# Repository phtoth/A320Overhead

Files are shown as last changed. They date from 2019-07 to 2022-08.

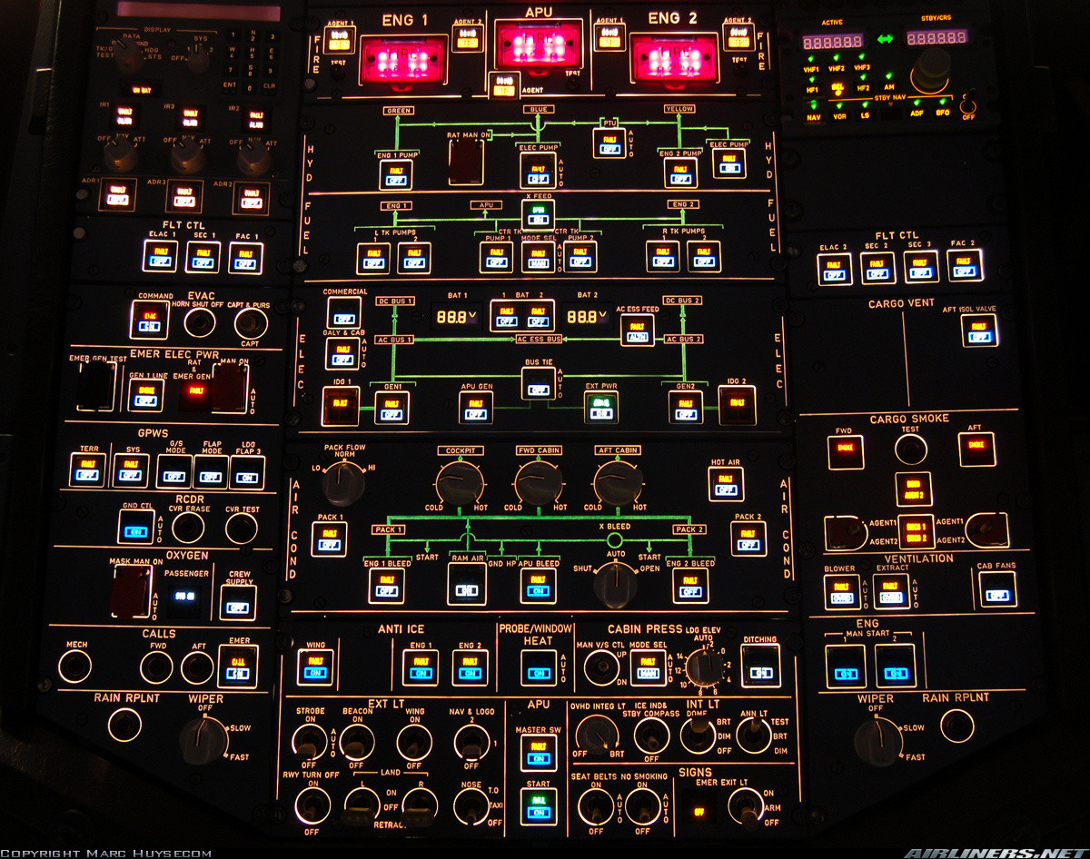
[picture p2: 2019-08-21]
Images that Help/crZPDkY.jpg

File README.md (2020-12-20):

# A320Overhead
A320 Overhead Project

Estrutura dos arquivos:
 - A320 AutoCAD Project - Projeto original do AutoCAD que está sendo modificado

 - Art - Os arquivos com os layouts originais da gravação a laser - com alguns erros :-(

 - Buttons - Projeto 3D dos botões dos painéis
      - Fire_Button - Botões de Controle de Incêndio
          - Button_Base - Base do botão que é colada na placa de acrílico
          - Button_Body - Corpo do Botão de Fire - o que mais demora para imprimir :-(
          - Button_Plate - Tampa com a inscrição "FIRE - Push"
          - Button_Extension - Mistakes Happen all the time

      - Korry - Botões no estilo Korry
          - Regular - Botões expostos, sem a proteção de acionamento
              - Horizontal - Apoio de fixação na horizontal do botão
              - Vertical - Apoio de fixação da vertical do botão
          - Stickers - Arquivos com os textos que ficam nos botões
      - Protected - Korrys que são protegidos    
          - Korry_Protected_Base - Base para segurar a capa de proteção do Korry
          - Korry_Protected_Shield - Capa protetora do Korry

      - Single_Protected_PB - Botões simples que são protegidos
          - Single_Protected_Base - Base dos botões que são protegidos
          - Single_Protected_Pin - Pino do botão
          - Single_Protected_Shield - Capa protetora dos botões protegidos
      - Button List.xlsx - Uma Lista com todos os botões do projeto

 - Eletronics - Arquivos com projetos e esquemeas eletricos e eletrônicos
      - Korry_Circuit - Circuitos que vão ficar atrás dos Korry Buttons
      - Led_Status - Placa que irá mostrar um status visual dos sistemas em execução
      - Main_Board - Placa principal do projeto, que irá acomodar os Arduinos e demais componentes

 - Images that Help - Alguns prints para ajudar na montagem do projeto

 - old - Coisas do projeto antigo - apagar no final

 - Panels - Diretório onde ficam os arquivos dos painéis
      - Light - Sistema de Iluminação do A320
          - Cut - Arquivo com os fontes para o corte a laser do painel
          - Draw - Arquivos para a pintura / gravação dos textos e setas
      - AirCond - Sistema de Ar Condicionado do A320
          - Cut - Arquivo com os fontes para o corte a laser do painel
          - Draw - Arquivos para a pintura / gravação dos textos e setas
      - Elec - Sistema Elétrico do A320
          - Cut - Arquivo com os fontes para o corte a laser do painel
          - Draw - Arquivos para a pintura / gravação dos textos e setas
      - Hyd_Fuel - Sistema Hidráulico e de Combustível do A320
          - Cut - Arquivo com os fontes para o corte a laser do painel
          - Draw - Arquivos para a pintura / gravação dos textos e setas
      - Fire - Sistema Supressão de Incêndio do A320
          - Cut - Arquivo com os fontes para o corte a laser do painel
          - Draw - Arquivos para a pintura / gravação dos textos e setas
      - Extra Size - Paineis do meio e Laterais para um tamanho extra no Overhead.
          - Cut - Arquivo com os fontes para o corte a laser do painel
      - Right Panel - Painel do Lado direito
          - R_Blank - Painel em Branco para preencher espaço vazio
                - Cut - Arquivo com os fontes para o corte a laser do painel
          - R_Cargo_Smoke - Sistema de supressão de incêndio no galpão de cargas e outros sistemas
                - Cut - Arquivo com os fontes para o corte a laser do painel
                - Draw - Arquivos para a pintura / gravação dos textos e setas
          - R_FLT_CTL - Sistema de Flight Control
                - Cut - Arquivo com os fontes para o corte a laser do painel
                - Draw - Arquivos para a pintura / gravação dos textos e setas
          - R_Radio_01_Blank - Sistema Rádio 01 - TODO
                - Cut - Arquivo com os fontes para o corte a laser do painel
          - R_Radio_02_Blank - Sistema Rádio 02 - TODO
                - Cut - Arquivo com os fontes para o corte a laser do painel
      - Left Panel - Painel do Lado esquerdo
          - L_ADIRS - Sistema de Navegação Inercial
                - Cut - Arquivo com os fontes para o corte a laser do painel
                - Draw - Arquivos para a pintura / gravação dos textos e setas
          - L_BAT - Painel onde fica a Luz ON BAT do Adirs
                - Cut - Arquivo com os fontes para o corte a laser do painel
          - L_Blank - Painel em Branco para preencher espaço vazio
                - Cut - Arquivo com os fontes para o corte a laser do painel
          - L_EVAC - Sistema de Emergência do avião
                - Cut - Arquivo com os fontes para o corte a laser do painel
                - Draw - Arquivos para a pintura / gravação dos textos e setas
          - L_FLT_CTL - Sistema de Flight Control
                - Cut - Arquivo com os fontes para o corte a laser do painel
                - Draw - Arquivos para a pintura / gravação dos textos e setas

  - Manuais - Documentações importantes
     - Componentes.md - Lista de componentes usados no projeto

  - README.md - Este arquivo :-)

Disclaimer: "Este é um projeto open source. Os pontos de vistas aqui apresentados são apenas meus e não foram revistos ou aprovados pela Airbus. Os códigos, prospectos e o projeto com oum todo foram criados por mim. Estes não pertecem e nem foram retirados da Airbus. Eu não falo em nome da Airbus. A marca Airbus A320® e todos os logotipos relacionados são marcas registradas da Airbus SE na França e demais países."

Disclaimer: "This is an open source project. The views presented here are only mine and have not been reviewed or approved by Airbus. The codes, prospectuses and the project as a whole were created by me. These do not belong nor have they been withdrawn of Airbus. I don't speak for Airbus. The Airbus A320® brand and all related logos are registered trademarks of Airbus SE in France and other countries."

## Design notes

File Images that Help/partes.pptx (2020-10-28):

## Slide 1

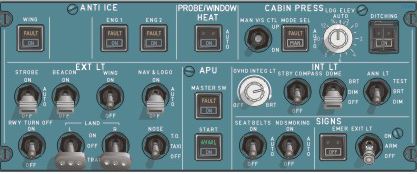
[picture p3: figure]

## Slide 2

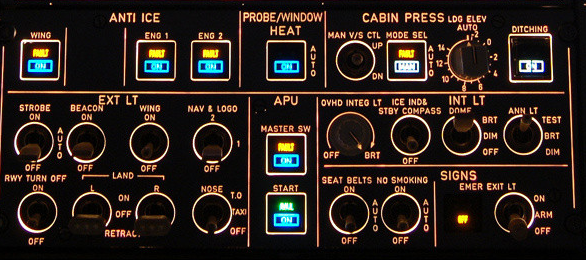
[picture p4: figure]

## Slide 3

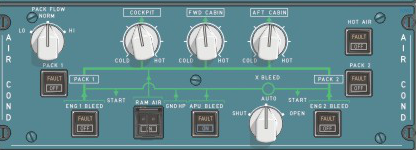
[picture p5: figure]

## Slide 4

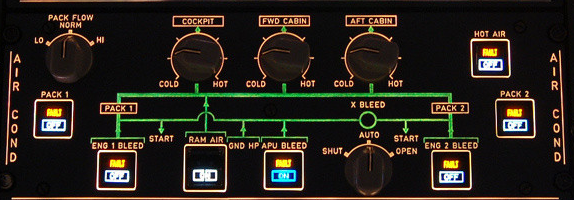
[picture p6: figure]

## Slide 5

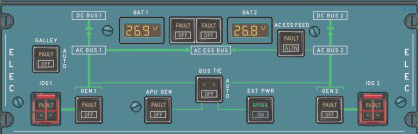
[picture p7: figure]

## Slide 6

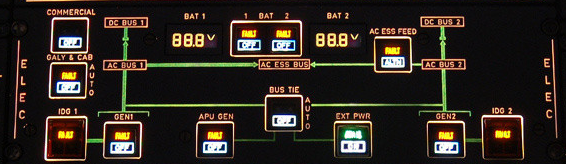
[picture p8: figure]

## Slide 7

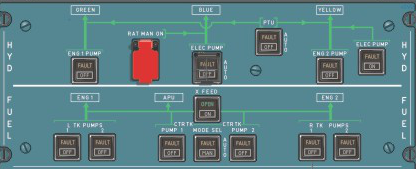
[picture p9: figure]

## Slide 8

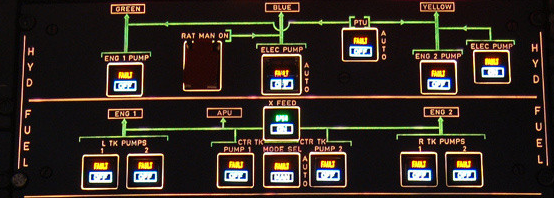
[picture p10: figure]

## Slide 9

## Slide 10

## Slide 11

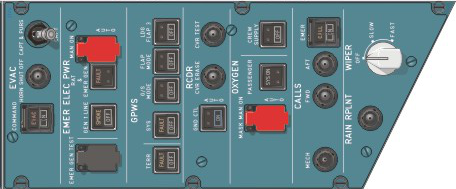
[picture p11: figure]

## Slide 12

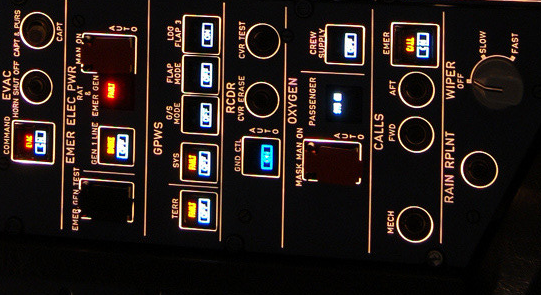
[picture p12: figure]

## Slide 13

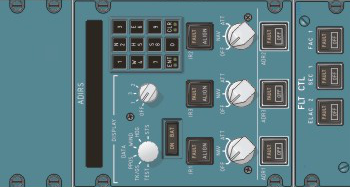
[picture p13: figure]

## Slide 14

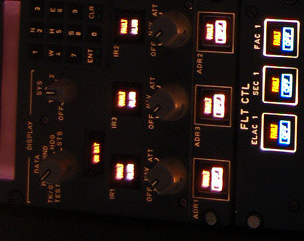
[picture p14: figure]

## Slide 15

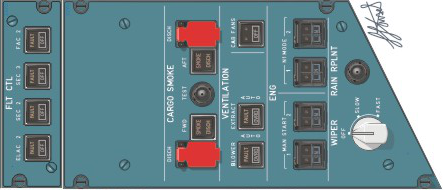
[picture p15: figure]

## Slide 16

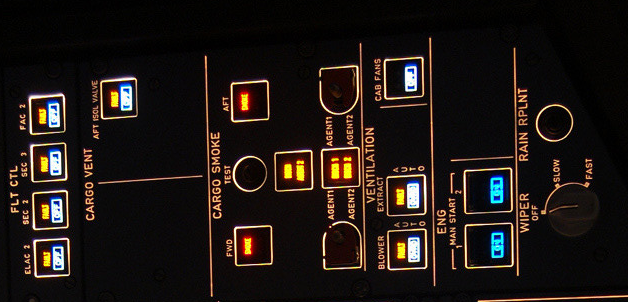
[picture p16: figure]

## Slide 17

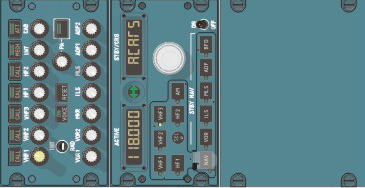
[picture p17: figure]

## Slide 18

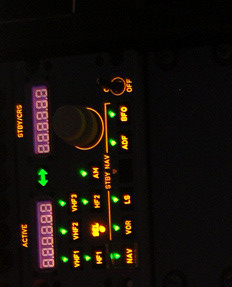
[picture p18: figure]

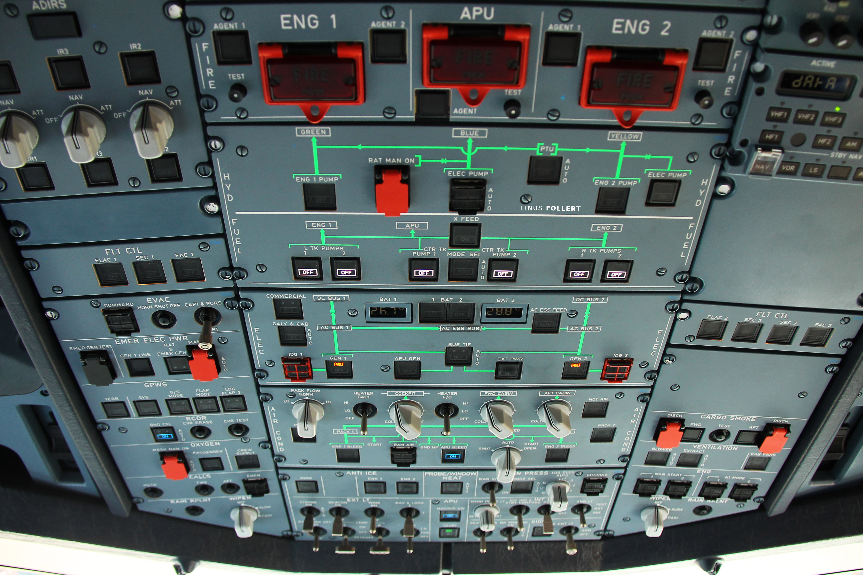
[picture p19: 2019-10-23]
Images that Help/14759350062_f6c9f7a548_o.jpg

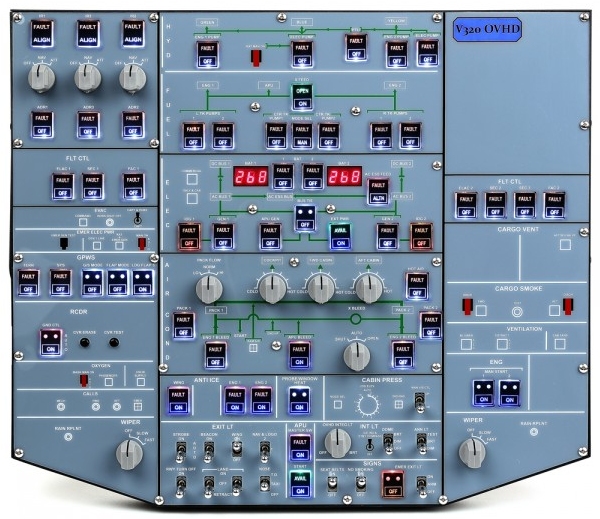
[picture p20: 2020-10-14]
Images that Help/VRI-225b.jpg

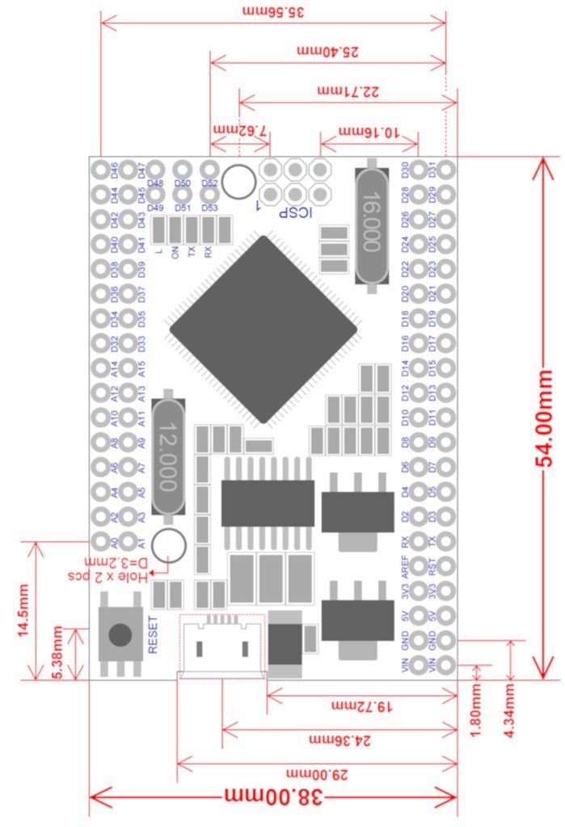
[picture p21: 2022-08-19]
Images that Help/ard-mega-pro_dimensions_zc_1024x1024.jpg

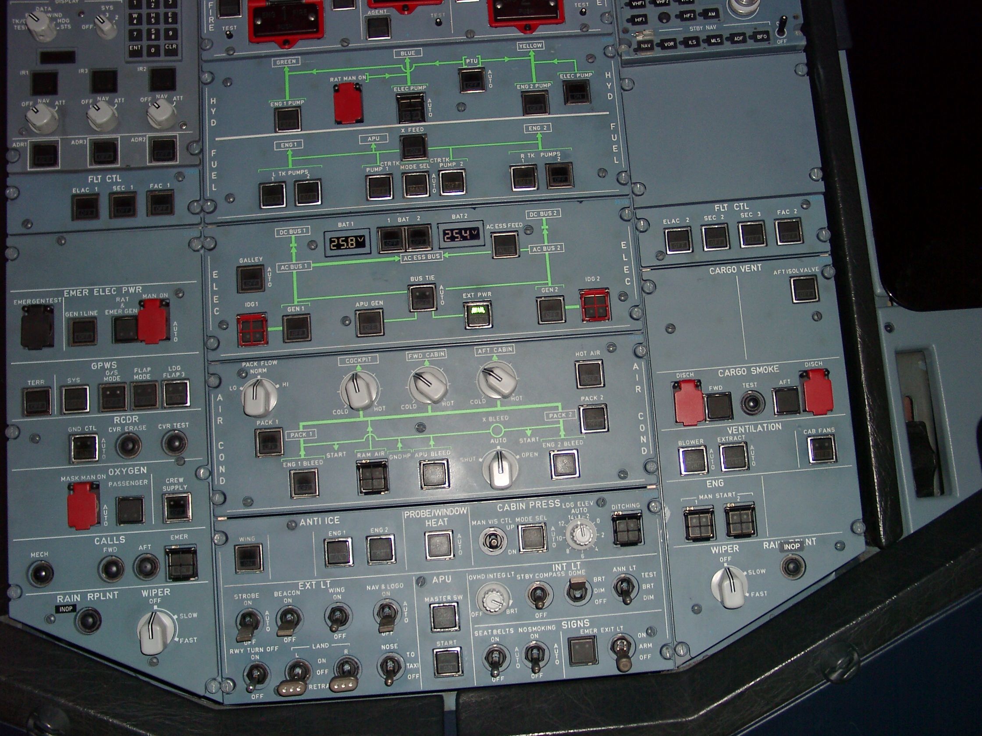
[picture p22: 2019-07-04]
Images that Help/lights.jpg

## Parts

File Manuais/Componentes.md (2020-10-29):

# Lista de componentes do Projeto
Segue a lista de materiais e quantidades necessárias para a montagem do projeto

## Compontente                                     Quantidade              Observação

Arduino MEGA 2560 Pro Mini ........................... 004 ................... 01                   
Arduino PORTENTA H7 .................................. 001 ................... 02
74HC595 - DIP ........................................ 032
Soquete para CI 16 pinos ............................. 032
Porta Fusível para Microondas de 30mm ................ 001 ................... 03 
Transistor Transistor NPN TIP41C ..................... 010
Dissipador de calor para TIP41C ...................... 010
Resistor 470 ohms (1/2/3 Watts) ...................... 010
Potenciometro Linear 47K ............................. 001
Soquete para CI 8 pinos .............................. 001
Cirtuito Integrado LM555 ............................. 001
Capacitor Cerâmico 100nF / 50V (104) ................. 002
Resistor 1K (1/2/3 Watts) ............................ 001
Relay SRD-05VDC-SL-C ................................. 003
Female Header 2.54 - 1x2 ............................. 004
Female Header 2.54 - 1x8 ............................. 008
Female Header 2.54 - 2x3 ............................. 008
Female Header 2.54 - 2x16 ............................ 004
Female Header 2.54 - 2x20 ............................ 004
Male / Female Header 2.54 - 1x1 ...................... 034 ................... 04
Male / Female Header 2.54 - 1x2 ...................... 005
Male / Female Header 2.54 - 1x3 ...................... 030
Male / Female Header 2.54 - 1x4 ...................... 001
Male / Female Header 2.54 - 1x5 ...................... 097
Male / Female Header 2.54 - 2x2 ...................... 001
Male / Female Header 2.54 - 2x5 ...................... 009
Male / Female Header 2.54 - 2x6 ...................... 007
Diodo 1N4007 ......................................... 014
Resistor 270 Ohms 1/4 Watt ........................... 181
Resistor 10K Ohm 1/4 Watt ............................ 144
Terminal KF128R-5.0-2P com passo de 5mm .............. 020

#### Obervações

01 - Se você for utilizar o Arduino Mega Mini como controlador geral do projeto, então a quantidade é 05.

02 - Se você Se você for utilizar o Arduino Mega Mini como controlador geral do projeto, então você não precisa deste componente. Ele foi escolhido para este projeto por sua capacidade dualcore. Cabe ressaltar também que vou me basear inicialmente no PORTENTA H7 como controlador principal, e que somente depois vou trabalhar em adaptações para o uso de um Mega Mini como controlador.

03 - Parecido com este: https://produto.mercadolivre.com.br/MLB-700023422-porta-fusivel-ceramica-20a-original-microondas-electrolux-_JM

04 - Os header marcados com Male / Female ficam a cargo do seu uso. Lembrando que, se você for usar conectores Male na placa, os seus conectores dos botões/leds deverão ser Female, e vice-versa.

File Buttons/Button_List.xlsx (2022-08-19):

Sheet: Iluminação
Codigo do Botão | Identificação | Tipo | Cod BTN | Orientação | QTD Leds | LED Bank | Cor 01 | LED Bank | Cor 02 | Texto 01 | Texto 02 | Tipo | Conexões Botão
1 | WING | Korry Regular | S_01_28_R | Horizontal | 2 | LED_BANK_04_A | Laranja | LED_BANK_04_B | Azul | FAULT | ON | Digital | 1
2 | ENG 1 | Korry Regular | S_01_29_R | Horizontal | 2 | LED_BANK_04_C | Laranja | LED_BANK_04_D | Azul | FAULT | ON | Digital | 1
3 | ENG 2 | Korry Regular | S_01_30_R | Horizontal | 2 | LED_BANK_04_E | Laranja | LED_BANK_04_F | Azul | FAULT | ON | Digital | 1
4 | STROBE | Seletor 3 Posições | S_01_04_R - S_01_05_R | - | - | - | - | - | - | - | - | Digital | 2
5 | BEACON | Seletor 2 Posições | S_01_24_R | - | - | - | - | - | - | - | - | Digital | 1
6 | WING | Seletor 2 Posições | S_01_25_R | - | - | - | - | - | - | - | - | Digital | 1
7 | NAV & LOGO | Seletor 3 Posições | S_01_06_R - S_01_07_R | - | - | - | - | - | - | - | - | Digital | 2
8 | RWY TURN OFF | Seletor 2 Posições | S_01_26_R | - | - | - | - | - | - | - | - | Digital | 1
9 | LAND L | Seletor 3 Posições | S_01_08_R - S_01_09_R | - | - | - | - | - | - | - | - | Digital | 2
10 | LAND R | Seletor 3 Posições | S_01_10_R - S_01_11_R | - | - | - | - | - | - | - | - | Digital | 2
11 | NOSE | Seletor 3 Posições | S_01_12_R - S_01_13_R | - | - | - | - | - | - | - | - | Digital | 2
12 | PROBE/WINDOW HEAT | Korry Regular | S_01_31_R | Horizontal | 1 | LED_BANK_04_G | - | - | Azul | - | ON | Digital | 1
13 | MASTER SW | Korry Regular | S_01_32_R | Horizontal | 2 | LED_BANK_04_H | Laranja | LED_BANK_05_A | Azul | FAULT | ON | Digital | 1
14 | START | Korry Regular | S_01_33_R | Horizontal | 2 | LED_BANK_05_B | Verde | LED_BANK_05_C | Azul | AVAIL | ON | Digital | 1
15 | MAN V/S CTL | Seletor 3 Posições | S_01_14_R - S_01_15_R | - | - | - | - | - | - | - | - | Digital | 2
16 | MODE SEL | Korry Regular | S_01_34_R | Horizontal | 2 | LED_BANK_05_D | Laranja | LED_BANK_05_E | Branco | FAULT | MAN | Digital | 1
17 | LDG ELEV | Seletor Livre | A01 | - | - |  | - |  | - |  |  | Analógico | 1
18 | DITCHING | Korry Protegido Preto | S_01_35_R | Horizontal | 1 | LED_BANK_05_F | - | - | Branco | - | ON | Digital | 1
19 | OVHD INTEG LT ** | Seletor Livre | *** | - | - | - | - | - | - | - | - | *** | ***
20 | ICE IND & STBY COMPASS | Seletor 2 Posições | S_01_27_R | - | - | - | - | - | - | - | - | Digital | 1
21 | DOME ** | Seletor 3 Posições | *** | - | - | - | - | - | - | - | - | *** | ***
22 | ANN LT | Seletor 3 Posições | S_01_16_R - S_01_17_R | - | - | - | - | - | - | - | - | Digital | 2
23 | SEAT BELTS | Seletor 3 Posições | S_01_18_R - S_01_19_R | - | - | - | - | - | - | - | - | Digital | 2
24 | NO SMOKING | Seletor 3 Posições | S_01_20_R - S_01_21_R | - | - | - | - | - | - | - | - | Digital | 2
25 | EMER | Korry Regular | S_01_36_R | Horizontal | 1 | LED_BANK_05_G | - | - | Laranja | - | OFF | Digital | 1
26 | EXIT LT | Seletor 3 Posições | S_01_22_R - S_01_23_R | - | - | - | - | - | - | - | - | Digital | 2
 |  |  |  |  |  |  |  |  |  |  | Entradas Digitais |  | 33
 |  |  |  |  |  |  |  |  |  |  | Entradas Analógicas |  | 1
 |  |  |  |  |  |  |  |  |  |  | Total de Leds |  | 15
 |  |  |  |  |  |  |  |  |  |  | Led Azul |  | 6
 |  |  |  |  |  |  |  |  |  |  | Led Laranja |  | 6
 |  |  |  |  |  |  |  |  |  |  | Led Branco |  | 2
 |  |  |  |  |  |  |  |  |  |  | Led Verde |  | 1
 |  |  |  |  |  |  |  |  |  |  | Conferência Leds |  | 15

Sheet: Ar Condicionado
Codigo do Botão | Identificação | Tipo | Cod BTN | Orientação | QTD Leds | LED Bank | Cor 01 | LED Bank | Cor 02 | Texto 01 | Texto 02 | Tipo | Conexões Botão
1 | PACK FLOW | Seletor Livre | A02 | - | - | - | - | - | - | - | - | Analógico | 1
2 | COCKPIT | Seletor Livre | A03 | - | - | - | - | - | - | - | - | Analógico | 1
3 | FWD CABIN | Seletor Livre | A04 | - | - | - | - | - | - | - | - | Analógico | 1
4 | AFT CABIN | Seletor Livre | A05 | - | - | - | - | - | - | - | - | Analógico | 1
5 | HOT AIR | Korry Regular | S_02_01_R | Horizontal | 2 | LED_BANK_05_H | Laranja | LED_BANK_06_A | Branco | FAULT | OFF | Digital | 1
6 | PACK 1 | Korry Regular | S_02_02_R | Horizontal | 2 | LED_BANK_06_B | Laranja | LED_BANK_06_C | Branco | FAULT | OFF | Digital | 1
7 | PACK2 | Korry Regular | S_02_03_R | Horizontal | 2 | LED_BANK_06_D | Laranja | LED_BANK_06_E | Branco | FAULT | OFF | Digital | 1
8 | ENG 1 BLEED | Korry Regular | S_02_04_R | Horizontal | 2 | LED_BANK_06_F | Laranja | LED_BANK_06_G | Branco | FAULT | OFF | Digital | 1
9 | RAM AIR | Korry Protegido Preto | S_02_05_R | Horizontal | 1 | - | - | LED_BANK_06_H | Branco | - | ON | Digital | 1
10 | APU BLEED | Korry Regular | S_02_06_R | Horizontal | 2 | LED_BANK_07_A | Laranja | LED_BANK_07_B | Azul | FAULT | ON | Digital | 1
11 | X-BLEED | Seletor Livre | A06 | - | - | - | - | - | - | - | - | Analógico | 1
12 | ENG 2 BLEED | Korry Regular | S_02_07_R | Horizontal | 2 | LED_BANK_07_C | Laranja | LED_BANK_07_D | Branco | FAULT | OFF | Digital | 1
 |  |  |  |  |  |  |  |  |  |  | Entradas Digitais |  | 7
 |  |  |  |  |  |  |  |  |  |  | Entradas Analógicas |  | 5
 |  |  |  |  |  |  |  |  |  |  | Total de Leds |  | 13
 |  |  |  |  |  |  |  |  |  |  | Led Azul |  | 1
 |  |  |  |  |  |  |  |  |  |  | Led Laranja |  | 6
 |  |  |  |  |  |  |  |  |  |  | Led Branco |  | 6
 |  |  |  |  |  |  |  |  |  |  | Conferência Leds |  | 13

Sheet: Elec
Codigo do Botão | Identificação | Tipo | Cod BTN | Orientação | QTD Leds | LED Bank | Cor 01 | LED Bank | Cor 02 | Texto 01 | Texto 02 | Tipo | Conexões Botão
1 | BAT 1 | Korry Regular | S_02_08_R | Vertical | 2 | LED_BANK_07_E | Laranja | LED_BANK_07_F | Branco | FAULT | OFF | Digital | 1
2 | BAT 2 | Korry Regular | S_02_09_R | Vertical | 2 | LED_BANK_07_G | Laranja | LED_BANK_07_H | Branco | FAULT | OFF | Digital | 1
3 | AC ESS FEED | Korry Regular | S_02_10_R | Horizontal | 2 | LED_BANK_08_A | Laranja | LED_BANK_08_B | Branco | FAULT | ALTN | Digital | 1
4 | GALLEY | Korry Regular | S_02_11_R | Horizontal | 2 | LED_BANK_08_C | Laranja | LED_BANK_08_D | Branco | FAULT | OFF | Digital | 1
5 | BUS TIE | Korry Regular | S_02_12_R | Horizontal | 1 | - | - | LED_BANK_08_E | Branco | - | OFF | Digital | 1
6 | IDG 1 | Korry Protegido Vermelho | S_02_13_R | Horizontal | 1 | LED_BANK_08_F | Laranja | - | - | FAULT | - | Digital | 1
7 | GEN 1 | Korry Regular | S_02_14_R | Horizontal | 2 | LED_BANK_08_G | Laranja | LED_BANK_08_H | Branco | FAULT | OFF | Digital | 1
8 | APU GEN | Korry Regular | S_02_15_R | Horizontal | 2 | LED_BANK_09_A | Laranja | LED_BANK_09_B | Branco | FAULT | OFF | Digital | 1
9 | EXT PWR | Korry Regular | S_02_16_R | Horizontal | 2 | LED_BANK_09_C | Verde | LED_BANK_09_D | Branco | AVAIL | ON | Digital | 1
10 | GEN 2 | Korry Regular | S_02_17_R | Horizontal | 2 | LED_BANK_09_E | Laranja | LED_BANK_09_F | Branco | FAULT | OFF | Digital | 1
11 | IDG 2 | Korry Protegido Vermelho | S_02_18_R | Horizontal | 1 | LED_BANK_09_G | Laranja | - | - | FAULT | - | Digital | 1
12 | LCD BAT 01 | DISPLAY Numérico | DISPLAY_01_01 - DISPLAY_01_03 | - | 24 | LED_BANK_10A-H | - |  | - | - | - | Digital | 3
12 | LCD BAT 02 | DISPLAY Numérico | DISPLAY_02_01 - DISPLAY_02_03 | - | 24 | LED_BANK_11A-H | - |  | - | - | - | Digital | 3
 |  |  |  |  |  |  |  |  |  |  | Entradas Digitais |  | 17
 |  |  |  |  |  |  |  |  |  |  | Entradas Analógicas |  | 0
 |  |  |  |  |  |  |  |  |  |  | Total de Leds |  | 67
 |  |  |  |  |  |  |  |  |  |  | Led Laranja |  | 9
 |  |  |  |  |  |  |  |  |  |  | Led Branco |  | 9
 |  |  |  |  |  |  |  |  |  |  | Led Verde |  | 1
 |  |  |  |  |  |  |  |  |  |  | Conferência Leds |  | 19

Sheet: Fuel
Codigo do Botão | Identificação | Tipo | Cod BTN | Orientação | QTD Leds | LED_Bank | Cor 01 | LED_Bank | Cor 02 | Texto 01 | Texto 02 | Tipo | Conexões Botão
1 | L TK PUMP 1 | Korry Regular | S_02_24_R | Vertical | 2 | LED_BANK_13_B | Laranja | LED_BANK_13_C | Branco | FAULT | OFF | Digital | 1
2 | L TK PUMP 2 | Korry Regular | S_02_19_R | Horizontal | 2 | LED_BANK_09_H | Laranja | LED_BANK_12_A | Branco | FAULT | OFF | Digital | 1
3 | X FEED | Korry Regular | S_02_20_R | Horizontal | 2 | LED_BANK_12_B | Verde | LED_BANK_12_C | Branco | OPEN | ON | Digital | 1
5 | CTR TK PUMP 1 | Korry Regular | S_02_21_R | Horizontal | 2 | LED_BANK_12_D | Laranja | LED_BANK_12_E | Branco | FAULT | OFF | Digital | 1
6 | MODE SEL | Korry Regular | S_02_25_R | Vertical | 2 | LED_BANK_13_D | Laranja | LED_BANK_13_E | Branco | FAULT | MAN | Digital | 1
7 | CTR TK PUMP 2 | Korry Regular | S_02_22_R | Horizontal | 2 | LED_BANK_12_F | Laranja | LED_BANK_12_G | Branco | FAULT | OFF | Digital | 1
8 | R TK PUMP 1 | Korry Regular | S_02_26_R | Vertical | 2 | LED_BANK_13_F | Laranja | LED_BANK_13_G | Branco | FAULT | OFF | Digital | 1
9 | R TK PUMP 2 | Korry Regular | S_02_23_R | Horizontal | 2 | LED_BANK_12_H | Laranja | LED_BANK_13_A | Branco | FAULT | OFF | Digital | 1
 |  |  |  |  |  |  |  |  |  |  | Entradas Digitais |  | 8
 |  |  |  |  |  |  |  |  |  |  | Entradas Analógicas |  | 0
 |  |  |  |  |  |  |  |  |  |  | Total de Leds |  | 16
 |  |  |  |  |  |  |  |  |  |  | Led Laranja |  | 7
 |  |  |  |  |  |  |  |  |  |  | Led Branco |  | 8
 |  |  |  |  |  |  |  |  |  |  | Led Verde |  | 1
 |  |  |  |  |  |  |  |  |  |  | Conferência Leds |  | 16

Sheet: Hyd
Codigo do Botão | Identificação | Tipo | Cod BTN | Orientação | QTD Leds | LED Bank | Cor 01 | LED Bank | Cor 02 | Texto 01 | Texto 02 | Tipo | Conexões Botão
1 | ENG 1 PUMP | Korry Regular | S_02_27_R | Horizontal | 2 | LED_BANK_13_H | Laranja | LED_BANK_14_A | Branco | FAULT | OFF | Digital | 1
2 | RAT MAN ON | Botão Com Capa Vermelha Fechada | S_02_28_R | - | 1 | LED_BANK_14_B | Branco | - | - | - | - | Digital | 1
3 | ELEC PUMP | Korry Protegido Preto | S_02_29_R | Horizontal | 2 | LED_BANK_14_C | Laranja | LED_BANK_14_D | Branco | FAULT | OFF | Digital | 1
5 | PTU | Korry Regular | S_02_30_R | Horizontal | 2 | LED_BANK_14_E | Laranja | LED_BANK_14_F | Branco | FAULT | OFF | Digital | 1
6 | ENG 2 PUMP | Korry Regular | S_02_31_R | Horizontal | 2 | LED_BANK_14_G | Laranja | LED_BANK_14_H | Branco | FAULT | OFF | Digital | 1
7 | ELEC PUMP | Korry Regular | S_02_32_R | Horizontal | 2 | LED_BANK_15_A | Laranja | LED_BANK_15_B | Branco | FAULT | ON | Digital | 1
 |  |  |  |  |  |  |  |  |  |  | Entradas Digitais |  | 6
 |  |  |  |  |  |  |  |  |  |  | Entradas Analógicas |  | 0
 |  |  |  |  |  |  |  |  |  |  | Total de Leds |  | 11
 |  |  |  |  |  |  |  |  |  |  | Led Laranja |  | 5
 |  |  |  |  |  |  |  |  |  |  | Led Branco |  | 6
 |  |  |  |  |  |  |  |  |  |  | Conferência Leds |  | 11

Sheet: Fire
Codigo do Botão | Identificação | Tipo | Cod BTN | Orientação | QTD Leds | LED Bank | Cor 01 | LED_Bank | Cor 02 | Texto 01 | Texto 02 | Tipo | Conexões Botão
1 | AGENT 1 | Korry Regular | S_02_33_R | Horizontal | 2 | LED_BANK_15_C | Branco | LED_BANK_15_D | Laranja | SQUIB | DISCH | Digital | 1
2 | TEST | Botão Simples | S_02_34_R | - | 1 | LED_BANK_15_E | Branco | - | - | - | - | Digital | 1
3 | ENG 1 FIRE | Botão Vermelho com Proteção Vermelha | S_01_01_R | - | 8 | LED_BANK_1_A--H | Vermelho | - | Vermelho | - | - | Digital | 1
5 | AGENT 2 | Korry Regular | S_02_35_R | Horizontal | 2 | LED_BANK_15_F | Branco | LED_BANK_15_G | Laranja | SQUIB | DISCH | Digital | 1
6 | APU FIRE | Botão Vermelho com Proteção Vermelha | S_01_02_R | - | 8 | LED_BANK_2_A--H | Vermelho | - | Vermelho | - | - | Digital | 1
7 | AGENT | Korry Regular | S_02_36_R | Horizontal | 2 | LED_BANK_15_H | Branco | LED_BANK_16_A | Laranja | SQUIB | DISCH | Digital | 1
10 | TEST | Botão Simples | S_03_01_R | - | 1 | LED_BANK_16_B | Branco | - | - | - | - | Digital | 1
11 | AGENT 1 | Korry Regular | S_03_02_R | Horizontal | 2 | LED_BANK_16_C | Branco | LED_BANK_16_D | Laranja | SQUIB | DISCH | Digital | 1
12 | ENG 2 FIRE | Botão Vermelho com Proteção Vermelha | S_01_03_R | - | 8 | LED_BANK_3_A--H | Vermelho | - | Vermelho | - | - | Digital | 1
13 | TEST | Botão Simples | S_03_03_R | - | 1 | LED_BANK_16_E | Branco | - | - | - | - | Digital | 1
14 | AGENT 2 | Korry Regular | S_03_04_R | Horizontal | 2 | LED_BANK_16_F | Branco | LED_BANK_16_G | Laranja | SQUIB | DISCH | Digital | 1
 |  |  |  |  |  |  |  |  |  |  | Entradas Digitais |  | 11
 |  |  |  |  |  |  |  |  |  |  | Entradas Analógicas |  | 0
 |  |  |  |  |  |  |  |  |  |  | Total de Leds |  | 37
 |  |  |  |  |  |  |  |  |  |  | Led Laranja |  | 5
 |  |  |  |  |  |  |  |  |  |  | Led Branco |  | 8
 |  |  |  |  |  |  |  |  |  |  | Led Vermelho |  | 24
 |  |  |  |  |  |  |  |  |  |  | Conferência Leds |  | 37

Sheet: Right_Side
Codigo do Botão | Identificação | Tipo | Cod BTN | Orientação | QTD Leds | LED Bank | Cor 01 | LED Bank | Cor 02 | Texto 01 | Texto 02 | Tipo | Conexões Botão
1 | WIPER | Seletor Livre | A07 | - | - | - | - | - | - | - | - | Analógico | 1
2 | RAIN RPLNT | Botão Simples | S_03_05_R | - | 1 | LED_BANK_16_H | Branco | - | - | - | - | Digital | 1
3 | ENG MAN START 1 | Korry Protegido Preto | S_03_06_R | Horizontal | 1 | - | - | LED_BANK_17_A | Azul | - | ON | Digital | 1
6 | N1 MODE 1 | Korry Protegido Preto | S_03_07_R | Horizontal | 1 | - | - | LED_BANK_17_B | Azul | - | ON | Digital | 1
10 | BLOWER | Korry Regular | S_03_08_R | Horizontal | 2 | LED_BANK_17_C | Laranja | LED_BANK_17_D | Branco | FAULT | OVRD | Digital | 1
11 | EXTRACT | Korry Regular | S_03_09_R | Horizontal | 2 | LED_BANK_17_E | Laranja | LED_BANK_17_F | Branco | FAULT | OVRD | Digital | 1
12 | CAB FANS | Korry Regular | S_03_10_R | Horizontal | 1 | - | - | LED_BANK_17_G | Branco | - | OFF | Digital | 1
13 | ELAC 2 | Korry Regular | S_03_11_R | Horizontal | 2 | LED_BANK_17_H | Laranja | LED_BANK_18_A | Branco | FAULT | OFF | Digital | 1
14 | SEC 3 | Korry Regular | S_03_12_R | Horizontal | 2 | LED_BANK_18_B | Laranja | LED_BANK_18_C | Branco | FAULT | OFF | Digital | 1
15 | DISCH | Botão Com Capa Vermelha Fechada | S_03_13_R | - | 1 | LED_BANK_18_D | Branco | - | - | - | - | Digital | 1
16 | ENG MAN START 2 | Korry Protegido Preto | S_03_14_R | Vertical | 1 | - | - | LED_BANK_18_E | Azul | - | ON | Digital | 1
17 | TEST | Botão Simples | S_03_15_R | - | 1 | LED_BANK_18_F | Branco | - | - | - | - | Digital | 1
18 | N1 MODE 2 | Korry Protegido Preto | S_03_16_R | Vertical | 1 | - | - | LED_BANK_18_G | Azul | - | ON | Digital | 1
19 | DISCH | Botão Com Capa Vermelha Fechada | S_03_17_R | - | 1 | LED_BANK_18_H | Branco | - | - | - | - | Digital | 1
20 | FWD | Korry Regular | S_03_18_R | Vertical | 2 | LED_BANK_19_A | Vermelho | LED_BANK_19_B | Laranja | SMOKE | DISCH | Digital | 1
21 | AFT | Korry Regular | S_03_19_R | Vertical | 2 | LED_BANK_19_C | Vermelho | LED_BANK_19_D | Laranja | SMOKE | DISCH | Digital | 1
22 | SEC 2 | Korry Regular | S_03_20_R | Vertical | 2 | LED_BANK_19_E | Laranja | LED_BANK_19_F | Branco | FAULT | OFF | Digital | 1
23 | FAC 3 | Korry Regular | S_03_21_R | Vertical | 2 | LED_BANK_19_G | Laranja | LED_BANK_19_H | Branco | FAULT | OFF | Digital | 1
 |  |  |  |  |  |  |  |  |  |  | Entradas Digitais |  | 17
 |  |  |  |  |  |  |  |  |  |  | Entradas Analógicas |  | 1
 |  |  |  |  |  |  |  |  |  |  | Total de Leds |  | 25
 |  |  |  |  |  |  |  |  |  |  | Led Laranja |  | 8
 |  |  |  |  |  |  |  |  |  |  | Led Branco |  | 11
 |  |  |  |  |  |  |  |  |  |  | Led Azul |  | 4
 |  |  |  |  |  |  |  |  |  |  | Led Vermelho |  | 2
 |  |  |  |  |  |  |  |  |  |  | Conferência Leds |  | 25

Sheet: Left_Side
Codigo do Botão | Identificação | Tipo | Cod BTN | Orientação | QTD Leds | LED Bank | Cor 01 | LED Bank | Cor 02 | Texto 01 | Texto 02 | Tipo | Conexões Botão
1 | WIPER | Seletor Livre | A08 | - | - | - | - | - | - | - | - | Analógico | 1
2 | RAIN RPLNT | Botão Simples | S_03_22_R | - | 1 | LED_BANK_20_A | Branco | - | - | - | - | Digital | 1
3 | EMER | Korry Protegido Preto | S_03_23_R | Horizontal | 2 | LED_BANK_20_B | Laranja | LED_BANK_20_C | Vermelho | CALL | ON | Digital | 1
6 | MECH | Botão Simples | S_03_24_R | - | 1 | LED_BANK_20_D | Branco | - | - | - | - | Digital | 1
10 | FWD | Botão Simples | S_03_25_R | - | 1 | LED_BANK_20_E | Branco | - | - | - | - | Digital | 1
11 | AFT | Botão Simples | S_03_26_R | - | 1 | LED_BANK_20_F | Branco | - | - | - | - | Digital | 1
12 | MASK MAN ON | Botão Com Capa Vermelha Fechada | S_03_27_R | - | 1 | LED_BANK_20_G | Branco | - | - | - | - | Digital | 1
13 | PASSENGER | Korry Regular | S_03_28_R | Horizontal | 1 | LED_BANK_20_H | Branco | - | - | SYS ON | - | Digital | 1
14 | CREW SUPPLY | Korry Regular | S_03_29_R | Horizontal | 1 | LED_BANK_21_A | Branco | - | - | - | OFF | Digital | 1
15 | GND CTL | Korry Regular | S_03_30_R | Horizontal | 1 | - | - | LED_BANK_21_B | Azul | - | ON | Digital | 1
16 | CVR ERASE | Botão Simples | S_03_31_R | - | 1 | LED_BANK_21_C | Branco | - | - | - | - | Digital | 1
17 | CVR TEST | Botão Simples | S_03_32_R | - | 1 | LED_BANK_21_D | Branco | - | - | - | - | Digital | 1
18 | TERR | Korry Regular | S_03_33_R | Horizontal | 2 | LED_BANK_21_E | Laranja | LED_BANK_21_F | Branco | FAULT | OFF | Digital | 1
19 | G/S MODE | Korry Regular | S_03_34_R | Horizontal | 1 | - | - | LED_BANK_21_G | Branco | - | OFF | Digital | 1
20 | LDG FLAP 3 | Korry Regular | S_03_35_R | Horizontal | 1 | - | - | LED_BANK_21_H | Branco | - | ON | Digital | 1
21 | GEN 1 LINE | Korry Regular | S_03_36_R | Horizontal | 2 | LED_BANK_22_A | Laranja | LED_BANK_22_B | Branco | SMOKE | OFF | Digital | 1
22 | COMMAND | Korry Protegido Preto | S_04_01_R | Horizontal | 2 | LED_BANK_22_C | Vermelho | LED_BANK_22_D | Branco | EVAC | ON | Digital | 1
23 | EMER GEN TEST | Botão Com Capa Preta Fechada | S_04_02_R | - | 1 | LED_BANK_22_E | Branco | - | - | - | - | Digital | 1
24 | ELAC 1 | Korry Regular | S_04_03_R | Horizontal | 2 | LED_BANK_22_F | Laranja | LED_BANK_22_G | Branco | FAULT | OFF | Digital | 1
25 | FAC 1 | Korry Regular | S_04_04_R | Horizontal | 2 | LED_BANK_22_H | Laranja | LED_BANK_23_A | Branco | FAULT | OFF | Digital | 1
26 | MAN ON | Botão Com Capa Vermelha Fechada | S_04_05_R | - | 1 | LED_BANK_23_B | Branco | - | - | - | - | Digital | 1
27 | ADR 1 | Korry Regular | S_04_06_R | Horizontal | 2 | LED_BANK_23_C | Laranja | LED_BANK_23_D | Branco | FAULT | OFF | Digital | 1
28 | HORN SHUT OFF | Botão Simples | S_04_07_R | - | 1 | LED_BANK_23_E | Branco | - | - | - | - | Digital | 1
29 | CAPT & PURS | Seletor 3 Posições | S_04_08_R - S_04_09_R | - | - | - | - | - | - | - | - | Digital | 2
30 | ADR 3 | Korry Regular | S_04_10_R | Horizontal | 2 | LED_BANK_23_F | Laranja | LED_BANK_23_G | Branco | FAULT | OFF | Digital | 1
31 | ADR 2 | Korry Regular | S_04_11_R | Horizontal | 2 | LED_BANK_23_H | Laranja | LED_BANK_24_A | Branco | FAULT | OFF | Digital | 1
32 | IR 1 | Korry Regular | S_04_12_R | Horizontal | 2 | LED_BANK_24_B | Laranja | LED_BANK_24_C | Branco | FAULT | ALIGN | Digital | 1
33 | IR 3 | Korry Regular | S_04_13_R | Horizontal | 2 | LED_BANK_24_D | Laranja | LED_BANK_24_E | Branco | FAULT | ALIGN | Digital | 1
34 | IR 2 | Korry Regular | S_04_14_R | Horizontal | 2 | LED_BANK_24_F | Laranja | LED_BANK_24_G | Branco | FAULT | ALIGN | Digital | 1
35 | SYS | Korry Regular | S_04_15_R | Vertical | 2 | LED_BANK_24_H | Laranja | LED_BANK_25_A | Branco | FAULT | OFF | Digital | 1
36 | NAV | Seletor Livre | A09 | - | - | - | - | - | - | - | - | Analógico | 1
37 | NAV | Seletor Livre | A10 | - | - | - | - | - | - | - | - | Analógico | 1
38 | NAV | Seletor Livre | A11 | - | - | - | - | - | - | - | - | Analógico | 1
39 | FLAP MODE | Korry Regular | S_04_16_R | Vertical | 1 | - | - | LED_BANK_25_B | Branco | - | OFF | Digital | 1
40 | RAT & EMER GEN | Korry Regular | S_04_17_R | Vertical | 1 | LED_BANK_25_C | Vermelho | - | - | FAULT | - | Digital | 1
41 | SEC 1 | Korry Regular | S_04_18_R | Vertical | 2 | LED_BANK_25_D | Laranja | LED_BANK_25_E | Branco | FAULT | OFF | Digital | 1
 |  |  |  |  |  |  |  |  |  |  | Entradas Digitais |  | 33
 |  |  |  |  |  |  |  |  |  |  | Entradas Analógicas |  | 4
 |  |  |  |  |  |  |  |  |  |  | Total de Leds |  | 45
 |  |  |  |  |  |  |  |  |  |  | Led Laranja |  | 13
 |  |  |  |  |  |  |  |  |  |  | Led Branco |  | 28
 |  |  |  |  |  |  |  |  |  |  | Led Azul |  | 1
 |  |  |  |  |  |  |  |  |  |  | Led Vermelho |  | 3
 |  |  |  |  |  |  |  |  |  |  | Conferência Leds |  | 45

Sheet: Totais
E/S Digital | 132
E/S Analógico | 11
Leds | 229
Led Driver | 29
E/S Digital + Led Drivers | 156
Controladoras CAN - Módulos | 6
E/S Dig + Led Drivers + CAN | 186
Número de Arduino - Módulos | 3
Arduino Master - Interface | 1
Led Laranja | 59
Led Azul | 12
Led Verde | 3
Led Branco | 78
Led Vermelho | 29
Displays Numéricos | 48
Conferência de Leds | 229

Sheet: Board_01_Buttons
Cod | Nome | Pinout | Tipo | Códigos Internos / Valores
1 | LDG ELEV | A01 | Analog | 100 | 0-255 | -
1 | ENG 1 FIRE | S_01_01_R | Korry | 1 | 2 | -
2 | PACK FLOW | A02 | Analog | 101 | 0-255 | -
2 | APU FIRE | S_01_02_R | Korry | 3 | 4 | -
3 | COCKPIT | A03 | Analog | 102 | 0-255 | -
3 | ENG 2 FIRE | S_01_03_R | Korry | 5 | 6 | -
4 | STROBE | S_01_05_R | 3 Pole | 7 | 8 | 9
4 | STROBE | S_01_04_R | 3 Pole | 10 | 11 | 12
4 | FWD CABIN | A04 | Analog | 103 | 0-255 | -
5 | NAV & LOGO | S_01_06_R | 3 Pole | 13 | 14 | 15
5 | NAV & LOGO | S_01_07_R | 3 Pole | 16 | 17 | 18
6 | LAND L | S_01_08_R | 3 Pole | 19 | 20 | 21
6 | LAND L | S_01_09_R | 3 Pole | 22 | 23 | 24
7 | LAND R | S_01_10_R | 3 Pole | 25 | 26 | 27
7 | LAND R | S_01_11_R | 3 Pole | 28 | 29 | 30
8 | NOSE | S_01_12_R | 3 Pole | 31 | 32 | 33
8 | NOSE | S_01_13_R | 3 Pole | 34 | 35 | 36
9 | MAN V/S CTL | S_01_14_R | 3 Pole | 37 | 38 | 39
9 | MAN V/S CTL | S_01_15_R | 3 Pole | 40 | 41 | 42
10 | ANN LT | S_01_16_R | 3 Pole | 43 | 44 | 45
10 | ANN LT | S_01_17_R | 3 Pole | 46 | 47 | 48
11 | SEAT BELTS | S_01_18_R | 3 Pole | 49 | 50 | 51
11 | SEAT BELTS | S_01_19_R | 3 Pole | 52 | 53 | 54
12 | NO SMOKING | S_01_20_R | 3 Pole | 55 | 56 | 57
12 | NO SMOKING | S_01_21_R | 3 Pole | 58 | 59 | 60
13 | EXIT LT | S_01_22_R | 3 Pole | 61 | 62 | 63
13 | EXIT LT | S_01_23_R | 3 Pole | 64 | 65 | 66
14 | BEACON | S_01_24_R | 2 Pole | 67 | 68 | -
15 | WING | S_01_25_R | 2 Pole | 69 | 70 | -
16 | RWY TURN OFF | S_01_26_R | 2 Pole | 71 | 72 | -
17 | ICE IND & STBY COMPASS | S_01_27_R | 2 Pole | 73 | 74 | -
18 | WING | S_01_28_R | Korry | 75 | 76 | -
19 | ENG 1 | S_01_29_R | Korry | 77 | 78 | -
20 | ENG 2 | S_01_30_R | Korry | 79 | 80 | -
21 | PROBE/WINDOW HEAT | S_01_31_R | Korry | 81 | 82 | -
22 | MASTER SW | S_01_32_R | Korry | 83 | 84 | -
23 | START | S_01_33_R | Korry | 85 | 86 | -
24 | MODE SEL | S_01_34_R | Korry | 87 | 88 | -
25 | DITCHING | S_01_35_R | Korry | 89 | 90 | -
26 | EMER | S_01_36_R | Korry | 91 | 92 | -

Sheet: Board_01_Leds
1 | A | Led_Bank_1 | ENG 1 FIRE
1 | B | Led_Bank_1 | ENG 1 FIRE
1 | C | Led_Bank_1 | ENG 1 FIRE
1 | D | Led_Bank_1 | ENG 1 FIRE
1 | E | Led_Bank_1 | ENG 1 FIRE
1 | F | Led_Bank_1 | ENG 1 FIRE
1 | G | Led_Bank_1 | ENG 1 FIRE
1 | H | Led_Bank_1 | ENG 1 FIRE
2 | A | Led_Bank_2 | APU FIRE
2 | B | Led_Bank_2 | APU FIRE
2 | C | Led_Bank_2 | APU FIRE
2 | D | Led_Bank_2 | APU FIRE
2 | E | Led_Bank_2 | APU FIRE
2 | F | Led_Bank_2 | APU FIRE
2 | G | Led_Bank_2 | APU FIRE
2 | H | Led_Bank_2 | APU FIRE
3 | A | Led_Bank_3 | ENG 2 FIRE
3 | B | Led_Bank_3 | ENG 2 FIRE
3 | C | Led_Bank_3 | ENG 2 FIRE
3 | D | Led_Bank_3 | ENG 2 FIRE
3 | E | Led_Bank_3 | ENG 2 FIRE
3 | F | Led_Bank_3 | ENG 2 FIRE
3 | G | Led_Bank_3 | ENG 2 FIRE
3 | H | Led_Bank_3 | ENG 2 FIRE
4 | A | Led_Bank_4 | WING
4 | B | Led_Bank_4 | WING
5 | C | Led_Bank_4 | ENG 1
5 | D | Led_Bank_4 | ENG 1
6 | E | Led_Bank_4 | ENG 2
6 | F | Led_Bank_4 | ENG 2
7 | G | Led_Bank_4 | PROBE/WINDOW HEAT
8 | H | Led_Bank_4 | MASTER SW
8 | A | Led_Bank_5 | MASTER SW
9 | B | Led_Bank_5 | START
9 | C | Led_Bank_5 | START
10 | D | Led_Bank_5 | MODE SEL
10 | E | Led_Bank_5 | MODE SEL
11 | F | Led_Bank_5 | DITCHING
12 | G | Led_Bank_5 | EMER
13 | H | Led_Bank_5 | HOT AIR
13 | A | Led_Bank_6 | HOT AIR
14 | B | Led_Bank_6 | PACK 1
14 | C | Led_Bank_6 | PACK 1
15 | D | Led_Bank_6 | PACK2
15 | E | Led_Bank_6 | PACK2
16 | F | Led_Bank_6 | ENG 1 BLEED
16 | G | Led_Bank_6 | ENG 1 BLEED
17 | H | Led_Bank_6 | RAM AIR
18 | A | Led_Bank_7 | APU BLEED
18 | B | Led_Bank_7 | APU BLEED
19 | C | Led_Bank_7 | ENG 2 BLEED
19 | D | Led_Bank_7 | ENG 2 BLEED
20 | E | Led_Bank_7 | BAT 1
20 | F | Led_Bank_7 | BAT 1
21 | G | Led_Bank_7 | BAT 2
21 | H | Led_Bank_7 | BAT 2
22 | A | Led_Bank_8 | AC ESS FEED
22 | B | Led_Bank_8 | AC ESS FEED
23 | C | Led_Bank_8 | GALLEY
23 | D | Led_Bank_8 | GALLEY
24 | E | Led_Bank_8 | BUS TIE
25 | F | Led_Bank_8 | IDG 1
26 | G | Led_Bank_8 | GEN 1
26 | H | Led_Bank_8 | GEN 1

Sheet: Board_02_Buttons
1 | HOT AIR | S_02_01_R
2 | PACK 1 | S_02_02_R
3 | PACK2 | S_02_03_R
4 | ENG 1 BLEED | S_02_04_R
5 | RAM AIR | S_02_05_R
6 | APU BLEED | S_02_06_R
7 | ENG 2 BLEED | S_02_07_R
8 | BAT 1 | S_02_08_R
9 | BAT 2 | S_02_09_R
10 | AC ESS FEED | S_02_10_R
11 | GALLEY | S_02_11_R
12 | BUS TIE | S_02_12_R
13 | IDG 1 | S_02_13_R
14 | GEN 1 | S_02_14_R
15 | APU GEN | S_02_15_R
16 | EXT PWR | S_02_16_R
17 | GEN 2 | S_02_17_R
18 | IDG 2 | S_02_18_R
19 | L TK PUMP 2 | S_02_19_R
20 | X FEED | S_02_20_R
21 | CTR TK PUMP 1 | S_02_21_R
22 | CTR TK PUMP 2 | S_02_22_R
23 | R TK PUMP 2 | S_02_23_R
24 | L TK PUMP 1 | S_02_24_R
25 | MODE SEL | S_02_25_R
26 | R TK PUMP 1 | S_02_26_R
27 | ENG 1 PUMP | S_02_27_R
28 | RAT MAN ON | S_02_28_R
29 | ELEC PUMP | S_02_29_R
30 | PTU | S_02_30_R
31 | ENG 2 PUMP | S_02_31_R
32 | ELEC PUMP | S_02_32_R
33 | AGENT 1 | S_02_33_R
34 | TEST | S_02_34_R
35 | AGENT 2 | S_02_35_R
36 | AGENT | S_02_36_R
1 | AFT CABIN | A05
2 | X-BLEED | A06
3 | WIPER | A07
4 | WIPER | A08

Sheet: Board_02_Leds
1 | A | Led_Bank_9 | APU GEN
1 | B | Led_Bank_9 | APU GEN
2 | C | Led_Bank_9 | EXT PWR
2 | D | Led_Bank_9 | EXT PWR
3 | E | Led_Bank_9 | GEN 2
3 | F | Led_Bank_9 | GEN 2
4 | G | Led_Bank_9 | IDG 2
5 | H | Led_Bank_9 | L TK PUMP 2
6 | A | Led_Bank_10 | LCD BAT 01
6 | B | Led_Bank_10 | LCD BAT 01
6 | C | Led_Bank_10 | LCD BAT 01
6 | D | Led_Bank_10 | LCD BAT 01
6 | E | Led_Bank_10 | LCD BAT 01
6 | F | Led_Bank_10 | LCD BAT 01
6 | G | Led_Bank_10 | LCD BAT 01
6 | H | Led_Bank_10 | LCD BAT 01
7 | A | Led_Bank_11 | LCD BAT 02
7 | B | Led_Bank_11 | LCD BAT 02
7 | C | Led_Bank_11 | LCD BAT 02
7 | D | Led_Bank_11 | LCD BAT 02
7 | E | Led_Bank_11 | LCD BAT 02
7 | F | Led_Bank_11 | LCD BAT 02
7 | G | Led_Bank_11 | LCD BAT 02
7 | H | Led_Bank_11 | LCD BAT 02
5 | A | Led_Bank_12 | L TK PUMP 2
8 | B | Led_Bank_12 | L TK PUMP 1
8 | C | Led_Bank_12 | L TK PUMP 1
9 | D | Led_Bank_12 | CTR TK PUMP 1
9 | E | Led_Bank_12 | CTR TK PUMP 1
10 | F | Led_Bank_12 | CTR TK PUMP 2
10 | G | Led_Bank_12 | CTR TK PUMP 2
11 | H | Led_Bank_12 | R TK PUMP 2
11 | A | Led_Bank_13 | R TK PUMP 2
12 | B | Led_Bank_13 | L TK PUMP 1
12 | C | Led_Bank_13 | L TK PUMP 1
13 | D | Led_Bank_13 | MODE SEL
13 | E | Led_Bank_13 | MODE SEL
14 | F | Led_Bank_13 | R TK PUMP 1
14 | G | Led_Bank_13 | R TK PUMP 1
15 | H | Led_Bank_13 | ENG 1 PUMP
15 | A | Led_Bank_14 | ENG 1 PUMP
16 | B | Led_Bank_14 | RAT MAN ON
17 | C | Led_Bank_14 | ELEC PUMP
17 | D | Led_Bank_14 | ELEC PUMP
18 | E | Led_Bank_14 | PTU
18 | F | Led_Bank_14 | PTU
19 | G | Led_Bank_14 | ENG 2 PUMP
19 | H | Led_Bank_14 | ENG 2 PUMP
20 | A | Led_Bank_15 | ELEC PUMP
20 | B | Led_Bank_15 | ELEC PUMP
21 | C | Led_Bank_15 | AGENT 1
21 | D | Led_Bank_15 | AGENT 1
22 | E | Led_Bank_15 | TEST
23 | F | Led_Bank_15 | AGENT 2
23 | G | Led_Bank_15 | AGENT 2
24 | H | Led_Bank_15 | AGENT
24 | A | Led_Bank_16 | AGENT
25 | B | Led_Bank_16 | TEST
26 | C | Led_Bank_16 | AGENT 1
26 | D | Led_Bank_16 | AGENT 1
27 | E | Led_Bank_16 | TEST
28 | F | Led_Bank_16 | AGENT 2
28 | G | Led_Bank_16 | AGENT 2
29 | H | Led_Bank_16 | RAIN RPLNT

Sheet: Board_03_Buttons
1 | Botão Simples | S_03_01_R
2 | Korry Regular | S_03_02_R
3 | Botão Simples | S_03_03_R
4 | Korry Regular | S_03_04_R
5 | RAIN RPLNT | S_03_05_R
6 | ENG MAN START 1 | S_03_06_R
7 | N1 MODE 1 | S_03_07_R
8 | BLOWER | S_03_08_R
9 | EXTRACT | S_03_09_R
10 | CAB FANS | S_03_10_R
11 | ELAC 2 | S_03_11_R
12 | SEC 3 | S_03_12_R
13 | DISCH | S_03_13_R
14 | ENG MAN START 2 | S_03_14_R
15 | TEST | S_03_15_R
16 | N1 MODE 2 | S_03_16_R
17 | DISCH | S_03_17_R
18 | FWD | S_03_18_R
19 | AFT | S_03_19_R
20 | SEC 2 | S_03_20_R
21 | FAC 3 | S_03_21_R
22 | RAIN RPLNT | S_03_22_R
23 | EMER | S_03_23_R
24 | MECH | S_03_24_R
25 | FWD | S_03_25_R
26 | AFT | S_03_26_R
27 | MASK MAN ON | S_03_27_R
28 | PASSENGER | S_03_28_R
29 | CREW SUPPLY | S_03_29_R
30 | GND CTL | S_03_30_R
31 | CVR ERASE | S_03_31_R
32 | CVR TEST | S_03_32_R
33 | TERR | S_03_33_R
34 | G/S MODE | S_03_34_R
35 | LDG FLAP 3 | S_03_35_R
36 | GEN 1 LINE | S_03_36_R
1 | NAV | A09
2 | NAV | A10
3 | NAV | A11
4 | A13 | A12
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

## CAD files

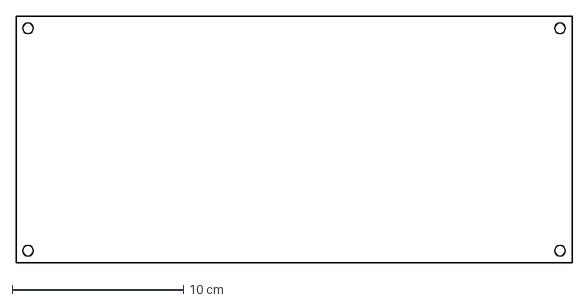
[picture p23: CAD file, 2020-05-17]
Panels/Extra Size/Cut/Extra_Main.dxf
32.5 x 14.4 cm

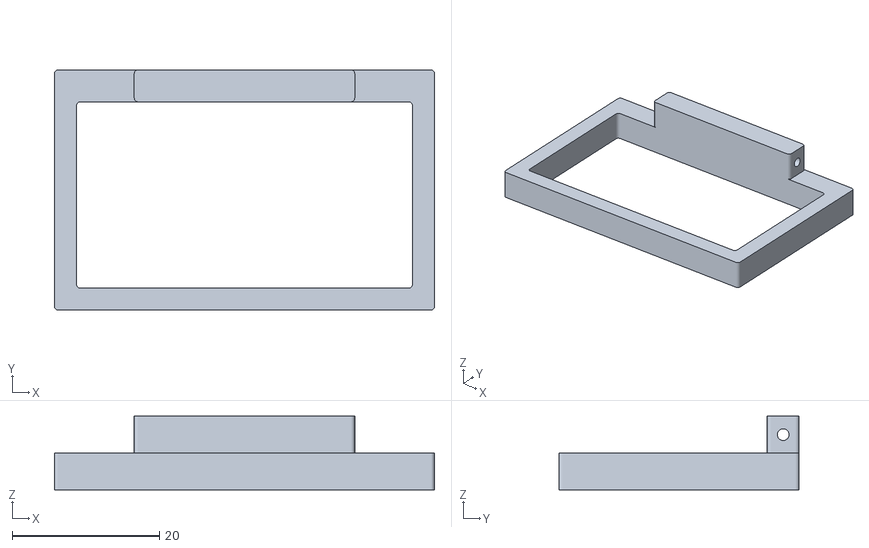
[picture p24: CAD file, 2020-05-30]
Buttons/Fire_Button/Button_Base/Button_Base.obj
51.7 x 32.7 x 10.0

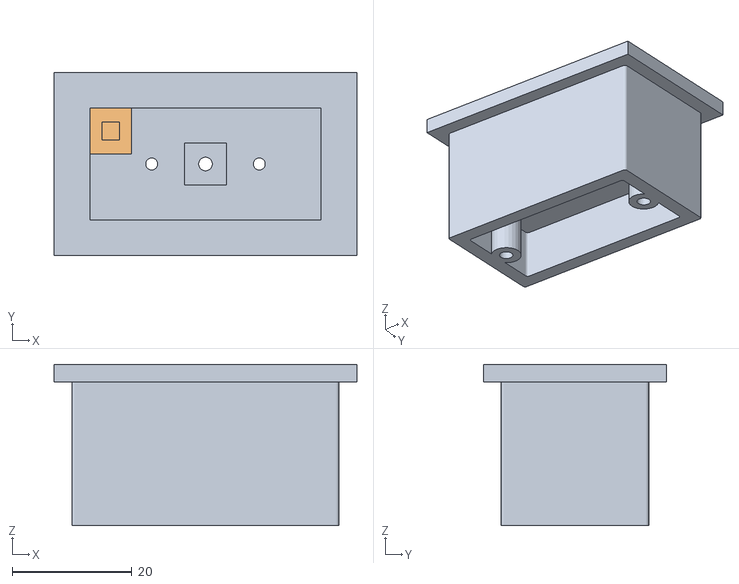
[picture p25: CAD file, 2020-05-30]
Buttons/Fire_Button/Button_Body/Button_Body.obj
50.7 x 30.7 x 27.0

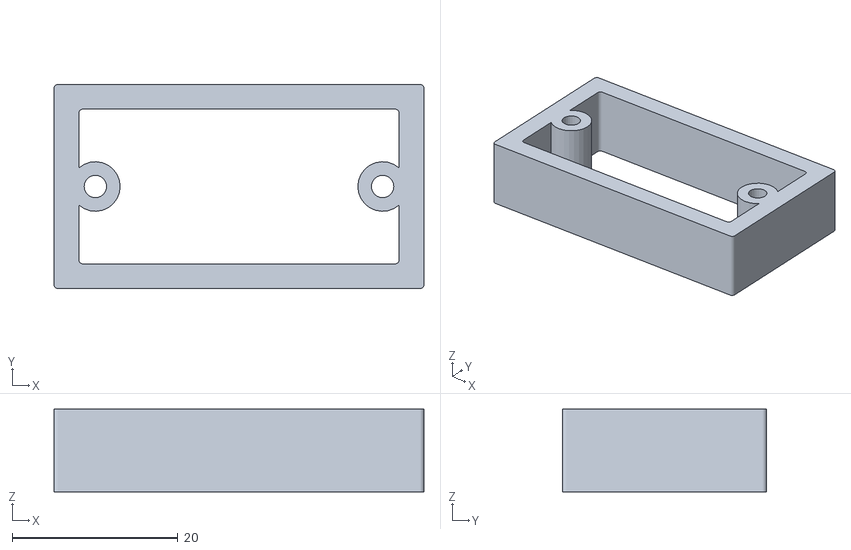
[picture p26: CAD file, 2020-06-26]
Buttons/Fire_Button/Button_Extension/Button_Extension.obj
44.7 x 24.7 x 10.0

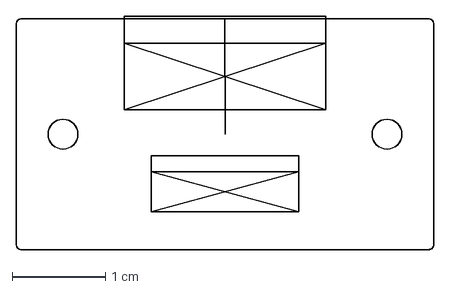
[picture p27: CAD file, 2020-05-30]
Buttons/Fire_Button/Button_Plate/Button_Plate.dxf
4.47 x 2.50 cm

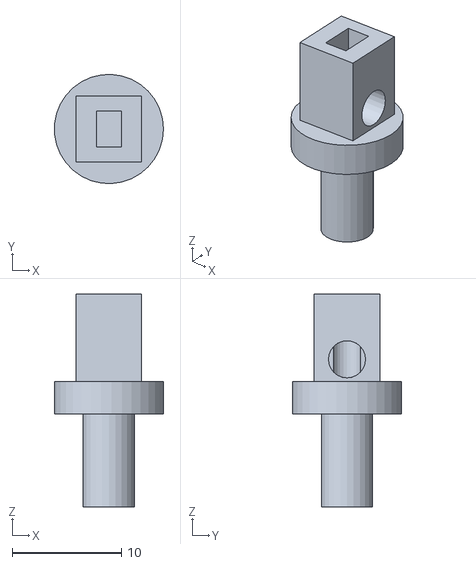
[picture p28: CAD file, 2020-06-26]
Buttons/Fire_Button/Test_PB/PB_Pino_FIre v4.obj
9.98 x 9.99 x 19.5

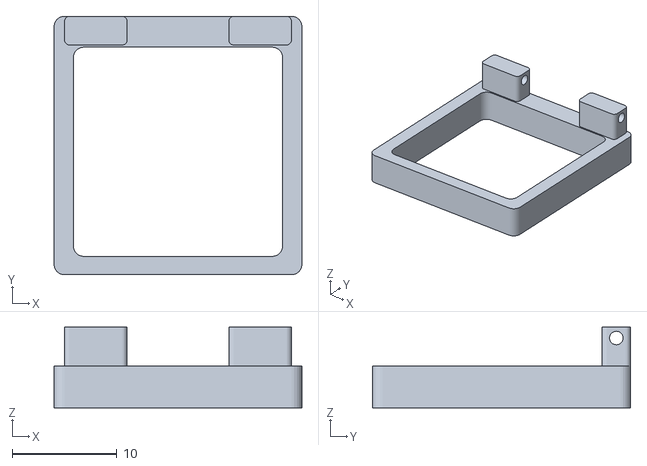
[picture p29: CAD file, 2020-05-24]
Buttons/Korry/Protected/Korry_Protected_Base/Korry_Protected_Base.obj
23.7 x 24.7 x 7.70

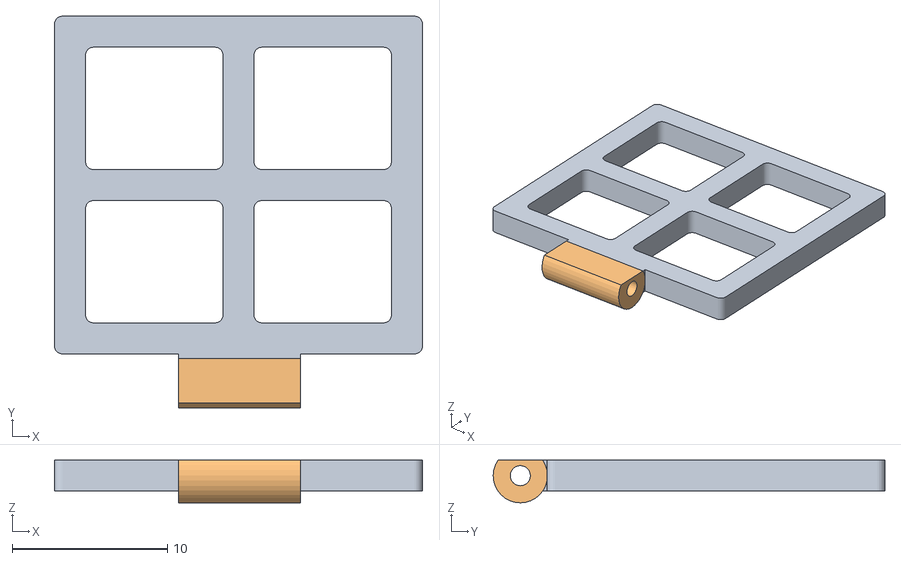
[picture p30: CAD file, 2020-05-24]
Buttons/Korry/Protected/Korry_Protected_Shield/Korry_Protected_Shield.obj
23.7 x 25.2 x 2.75

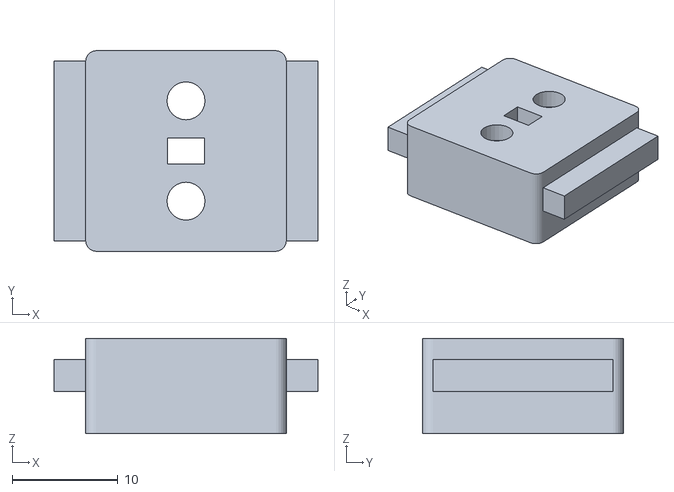
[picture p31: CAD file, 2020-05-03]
Buttons/Korry/Regular/Horizontal/Korry Horizontal.obj
25.0 x 19.0 x 9.00

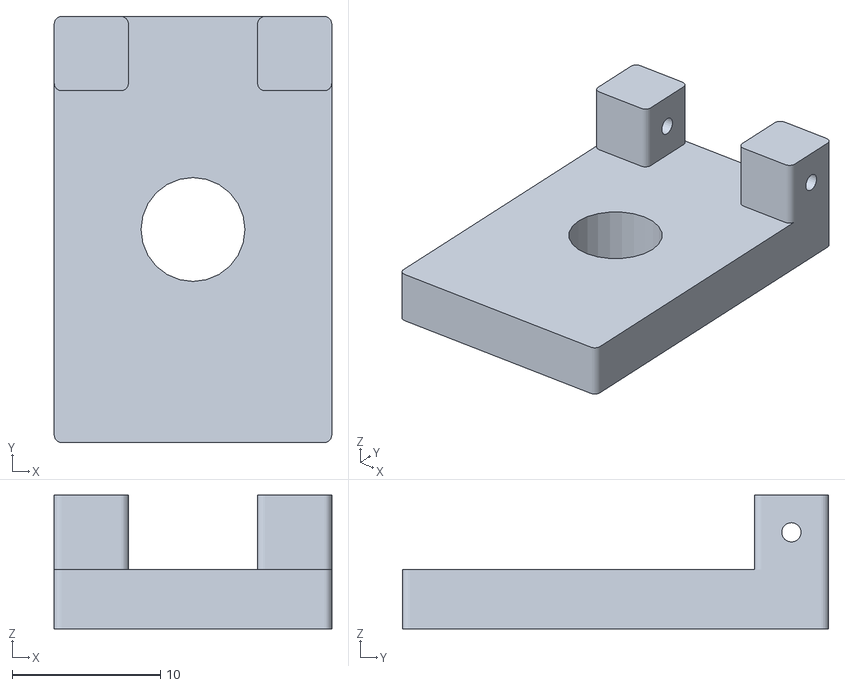
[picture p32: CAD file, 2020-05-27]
Buttons/Single_Protected_PB/Single_Protected_Base/Single_Protected_Base.obj
18.7 x 28.7 x 9.00

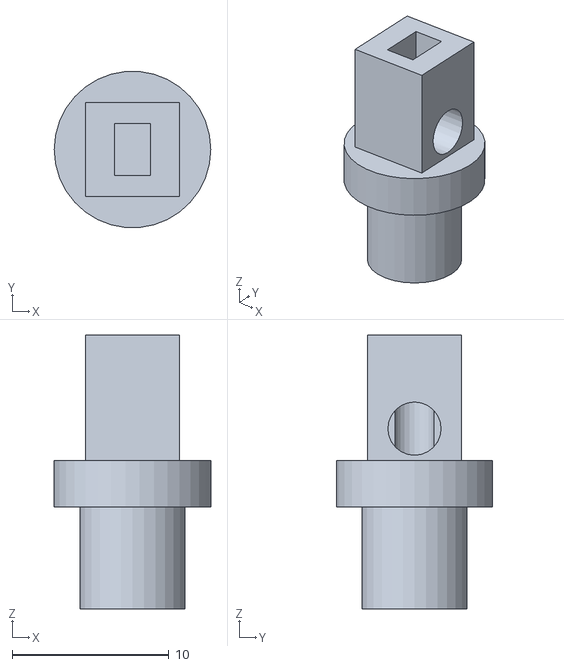
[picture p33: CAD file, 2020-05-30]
Buttons/Single_Protected_PB/Single_Protected_Pin/Single_Protected_Pin.obj
10.0 x 9.96 x 17.5

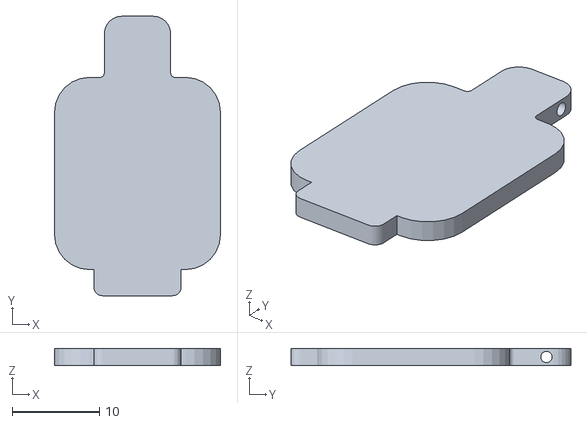
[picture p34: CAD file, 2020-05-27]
Buttons/Single_Protected_PB/Single_Protected_Shield/Single_Protected_Shield.obj
19.0 x 32.0 x 2.00

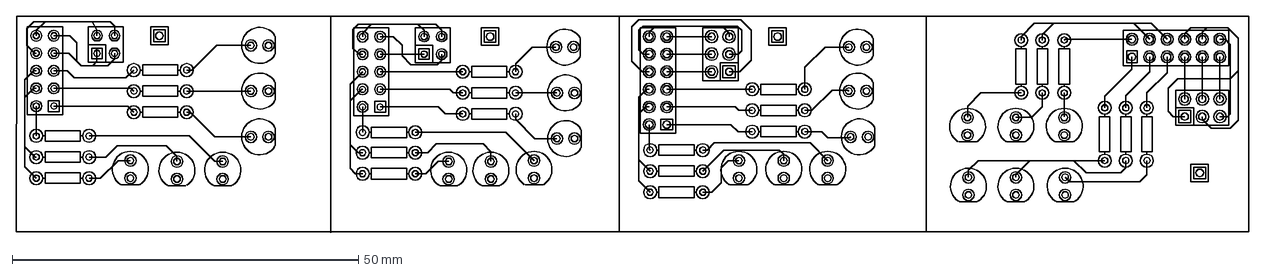
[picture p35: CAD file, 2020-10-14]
Eletronics/Led_Status/PCB_14-10-2020.dxf
178.1 x 31.3 mm

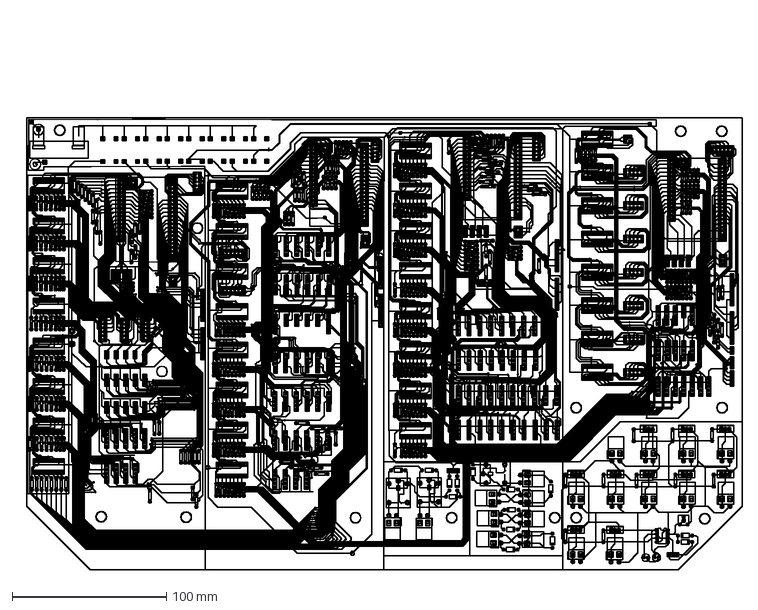
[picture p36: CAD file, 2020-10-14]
Eletronics/Main_Board/PCB_14-10-2020.dxf
471.2 x 359.4 mm

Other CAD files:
A320 AutoCAD Project/A320 PANELES.dwg
Buttons/Korry/Regular/Vertical/Korry Vertical.obj
Korry Switch/Base Korry_ditch v7.obj
Panels/AirCond/Air Cond v13.dxf
A320 AutoCAD Project/cubo_vivo v1.obj
Buttons/Fire_Button/Button_Base/Button_Base.dwg
Buttons/Fire_Button/Button_Base/Button_Base.dxf
Buttons/Fire_Button/Button_Base/Button_Base.f3d
Buttons/Fire_Button/Button_Body/Button_Body.dwg
Buttons/Fire_Button/Button_Body/Button_Body.dxf
Buttons/Fire_Button/Button_Body/Button_Body.f3d
Buttons/Fire_Button/Button_Extension/Button_Extension.dwg
Buttons/Fire_Button/Button_Extension/Button_Extension.dxf
Buttons/Fire_Button/Button_Extension/Button_Extension.f3d
Buttons/Fire_Button/Button_Plate/Button_Plate.dwg
Buttons/Fire_Button/Button_Plate/Button_Plate.f3d
Buttons/Korry/Protected/Korry_Protected_Base/Korry_Protected_Base.dwg
Buttons/Korry/Protected/Korry_Protected_Base/Korry_Protected_Base.dxf
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

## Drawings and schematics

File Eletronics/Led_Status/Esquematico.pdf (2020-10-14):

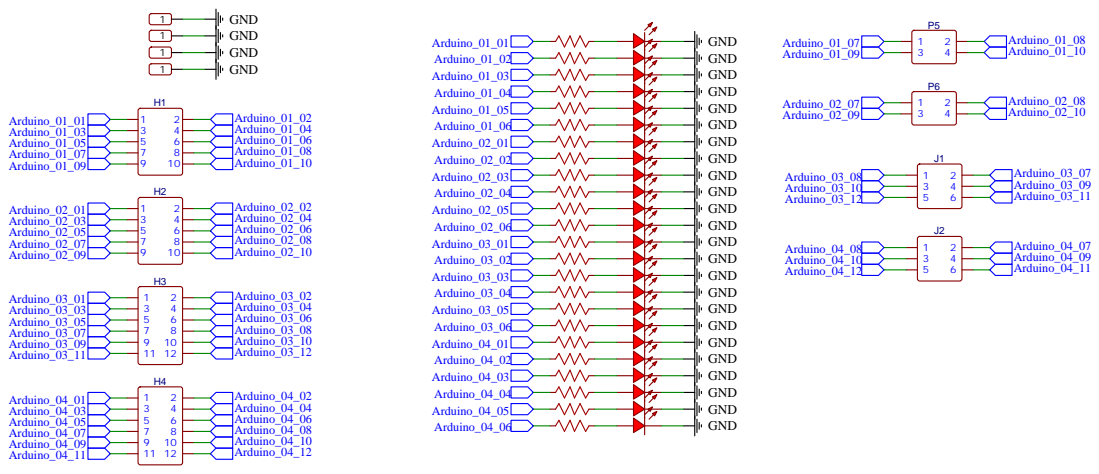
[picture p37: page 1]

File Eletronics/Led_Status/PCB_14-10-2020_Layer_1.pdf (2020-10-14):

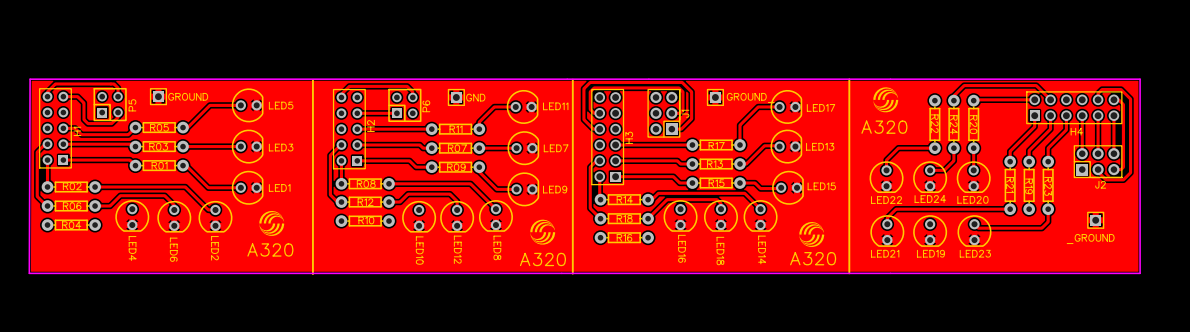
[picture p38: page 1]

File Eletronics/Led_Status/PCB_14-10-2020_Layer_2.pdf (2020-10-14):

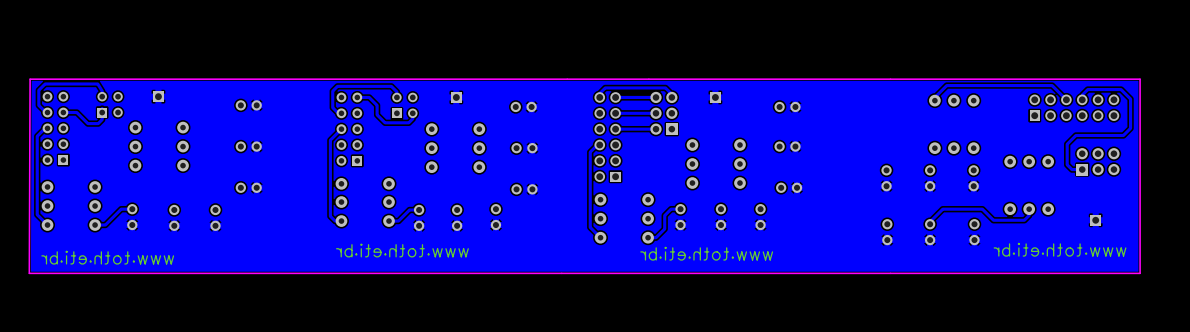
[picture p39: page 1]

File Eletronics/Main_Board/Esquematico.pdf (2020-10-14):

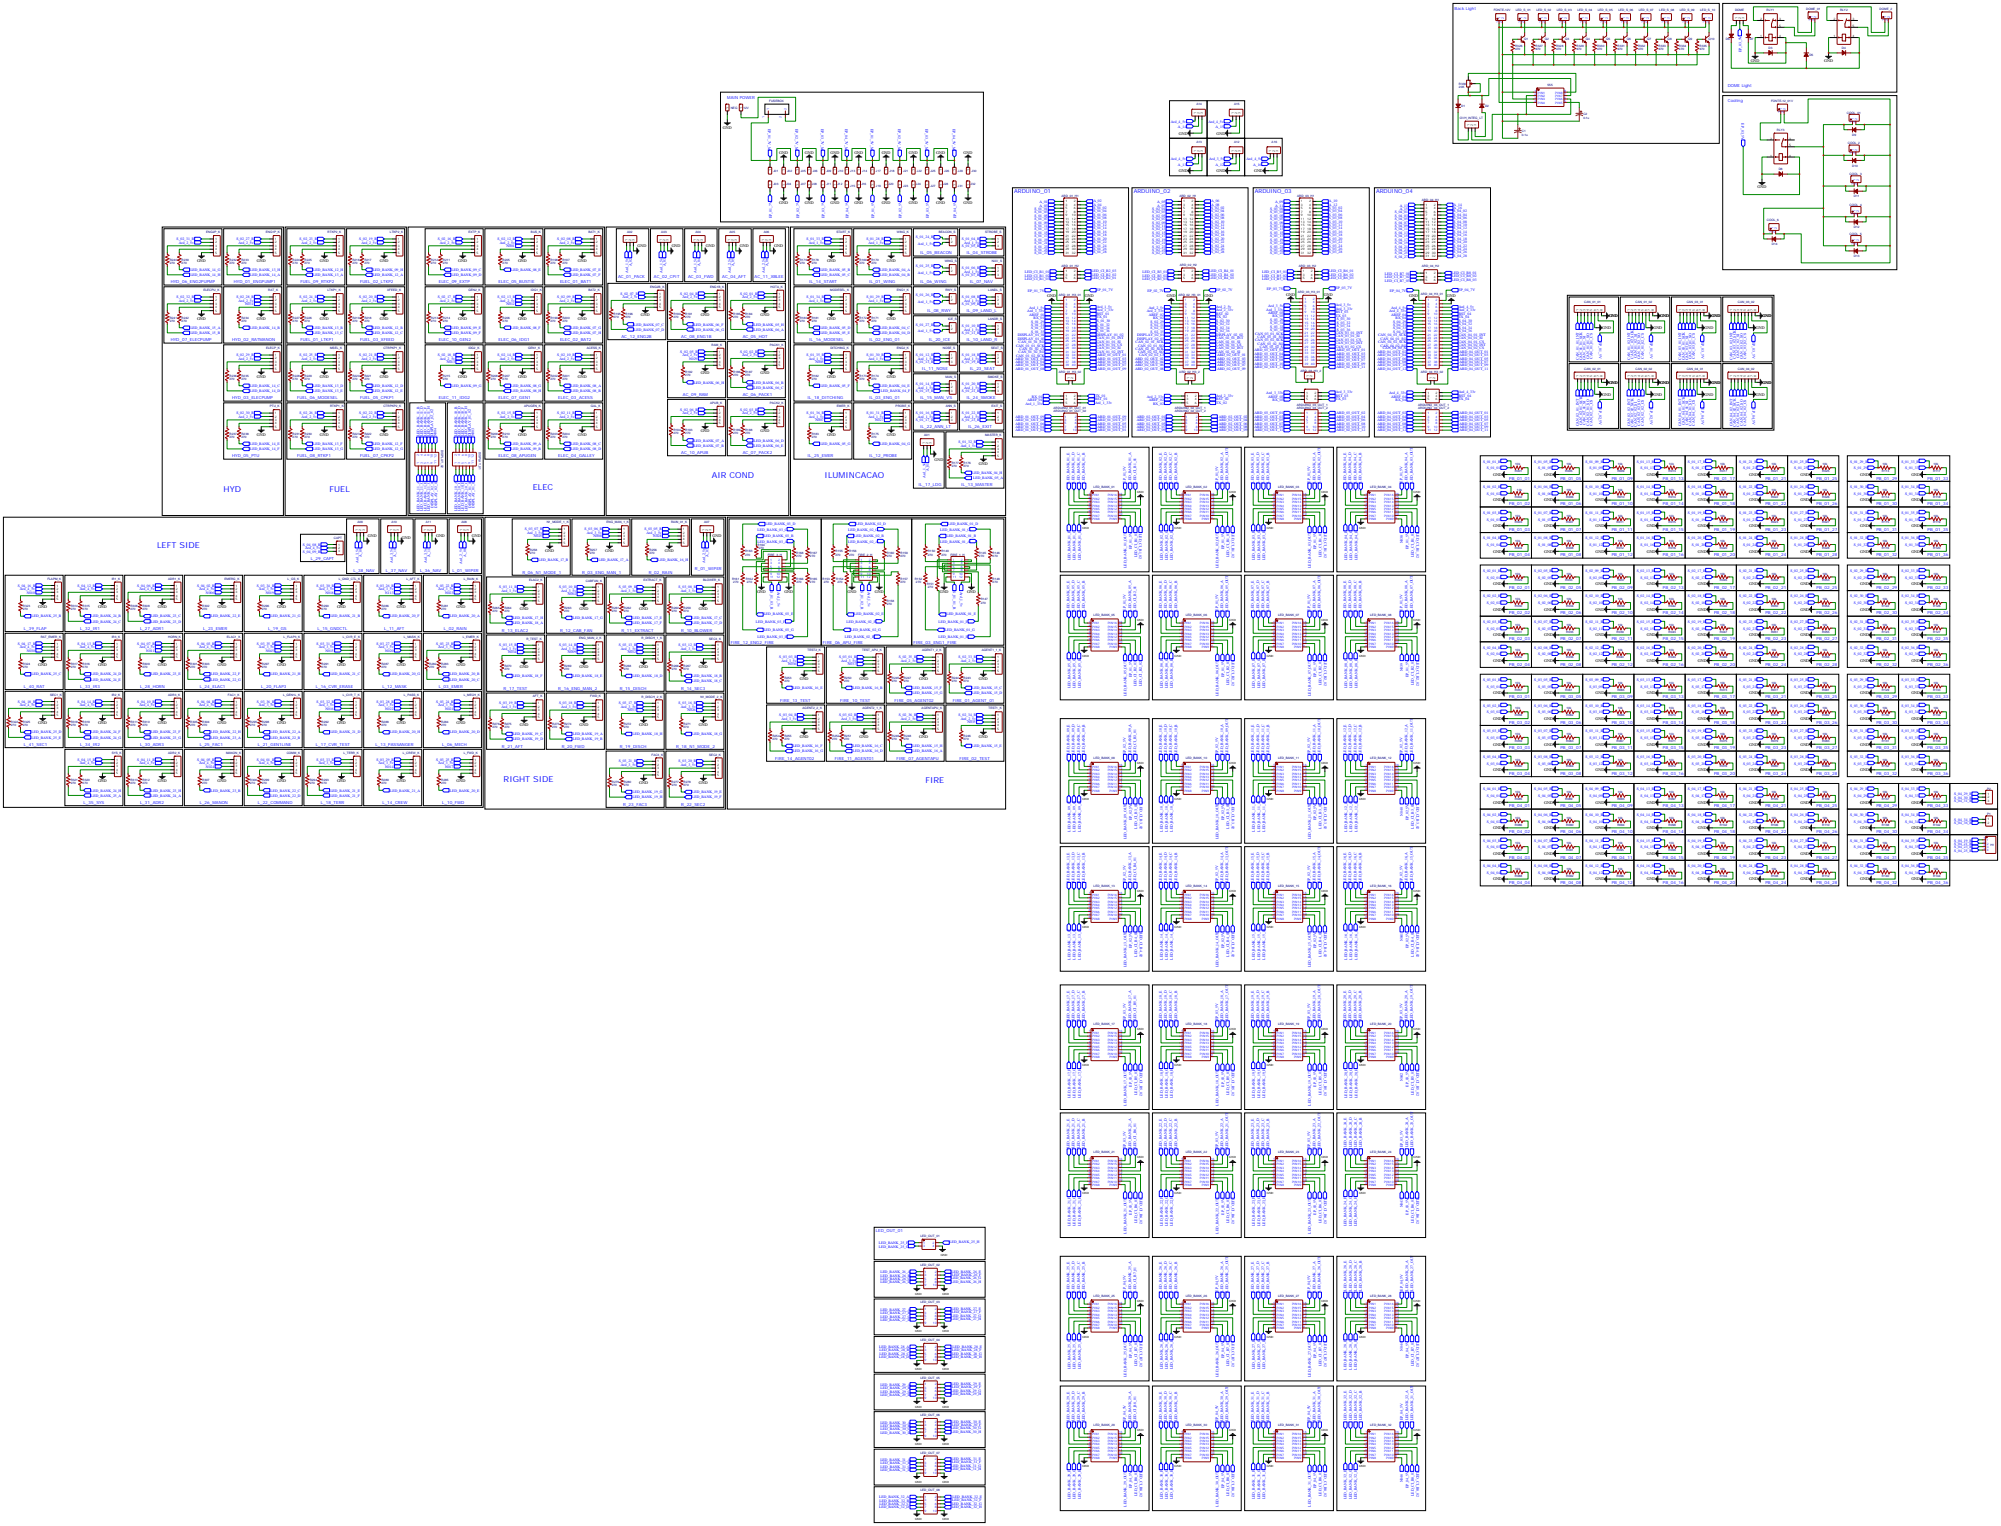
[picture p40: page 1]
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

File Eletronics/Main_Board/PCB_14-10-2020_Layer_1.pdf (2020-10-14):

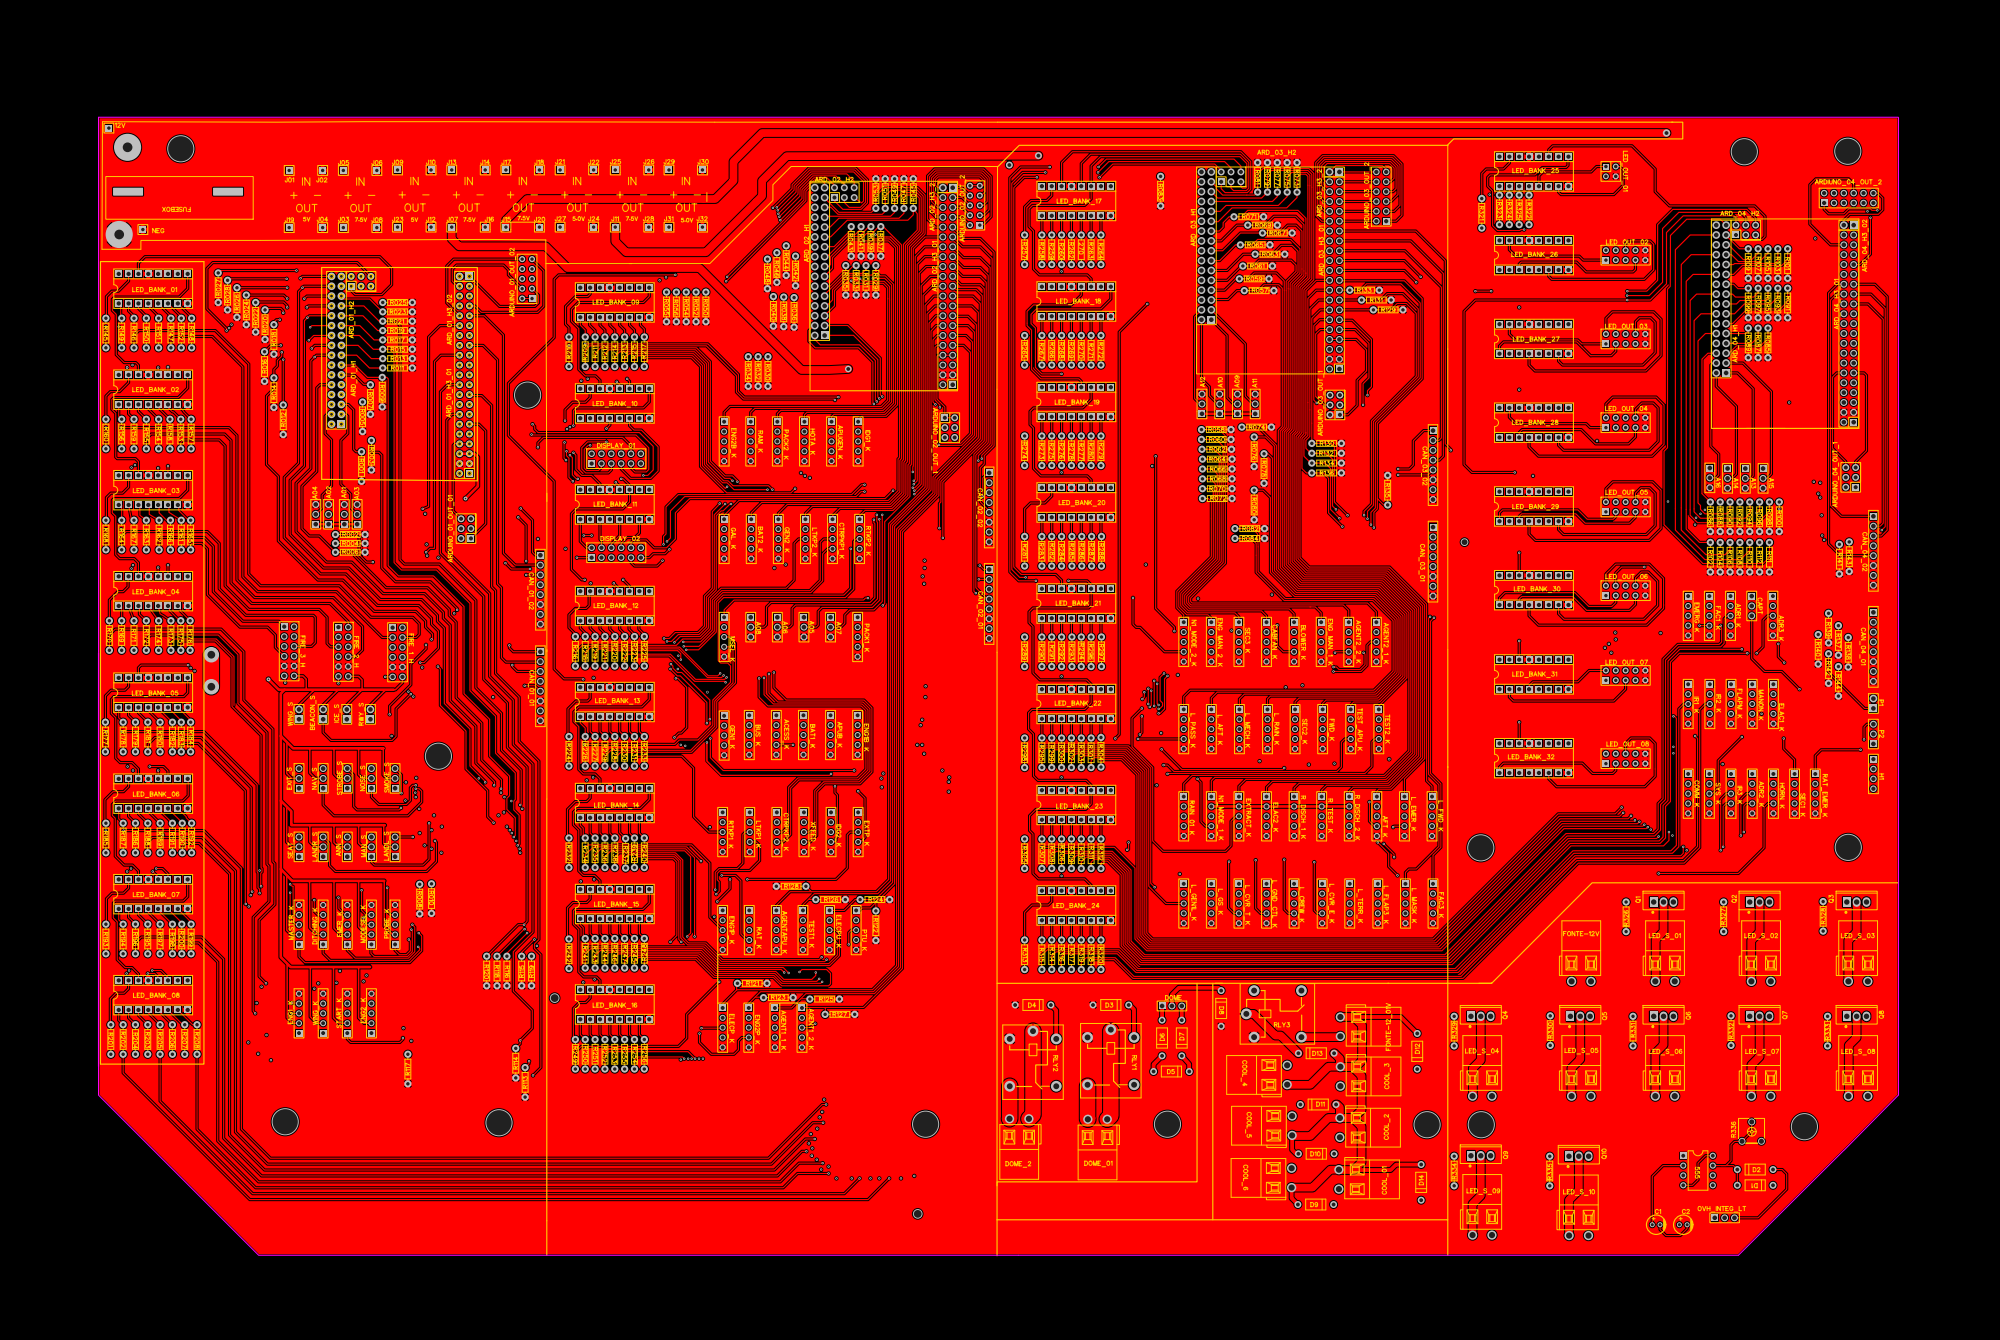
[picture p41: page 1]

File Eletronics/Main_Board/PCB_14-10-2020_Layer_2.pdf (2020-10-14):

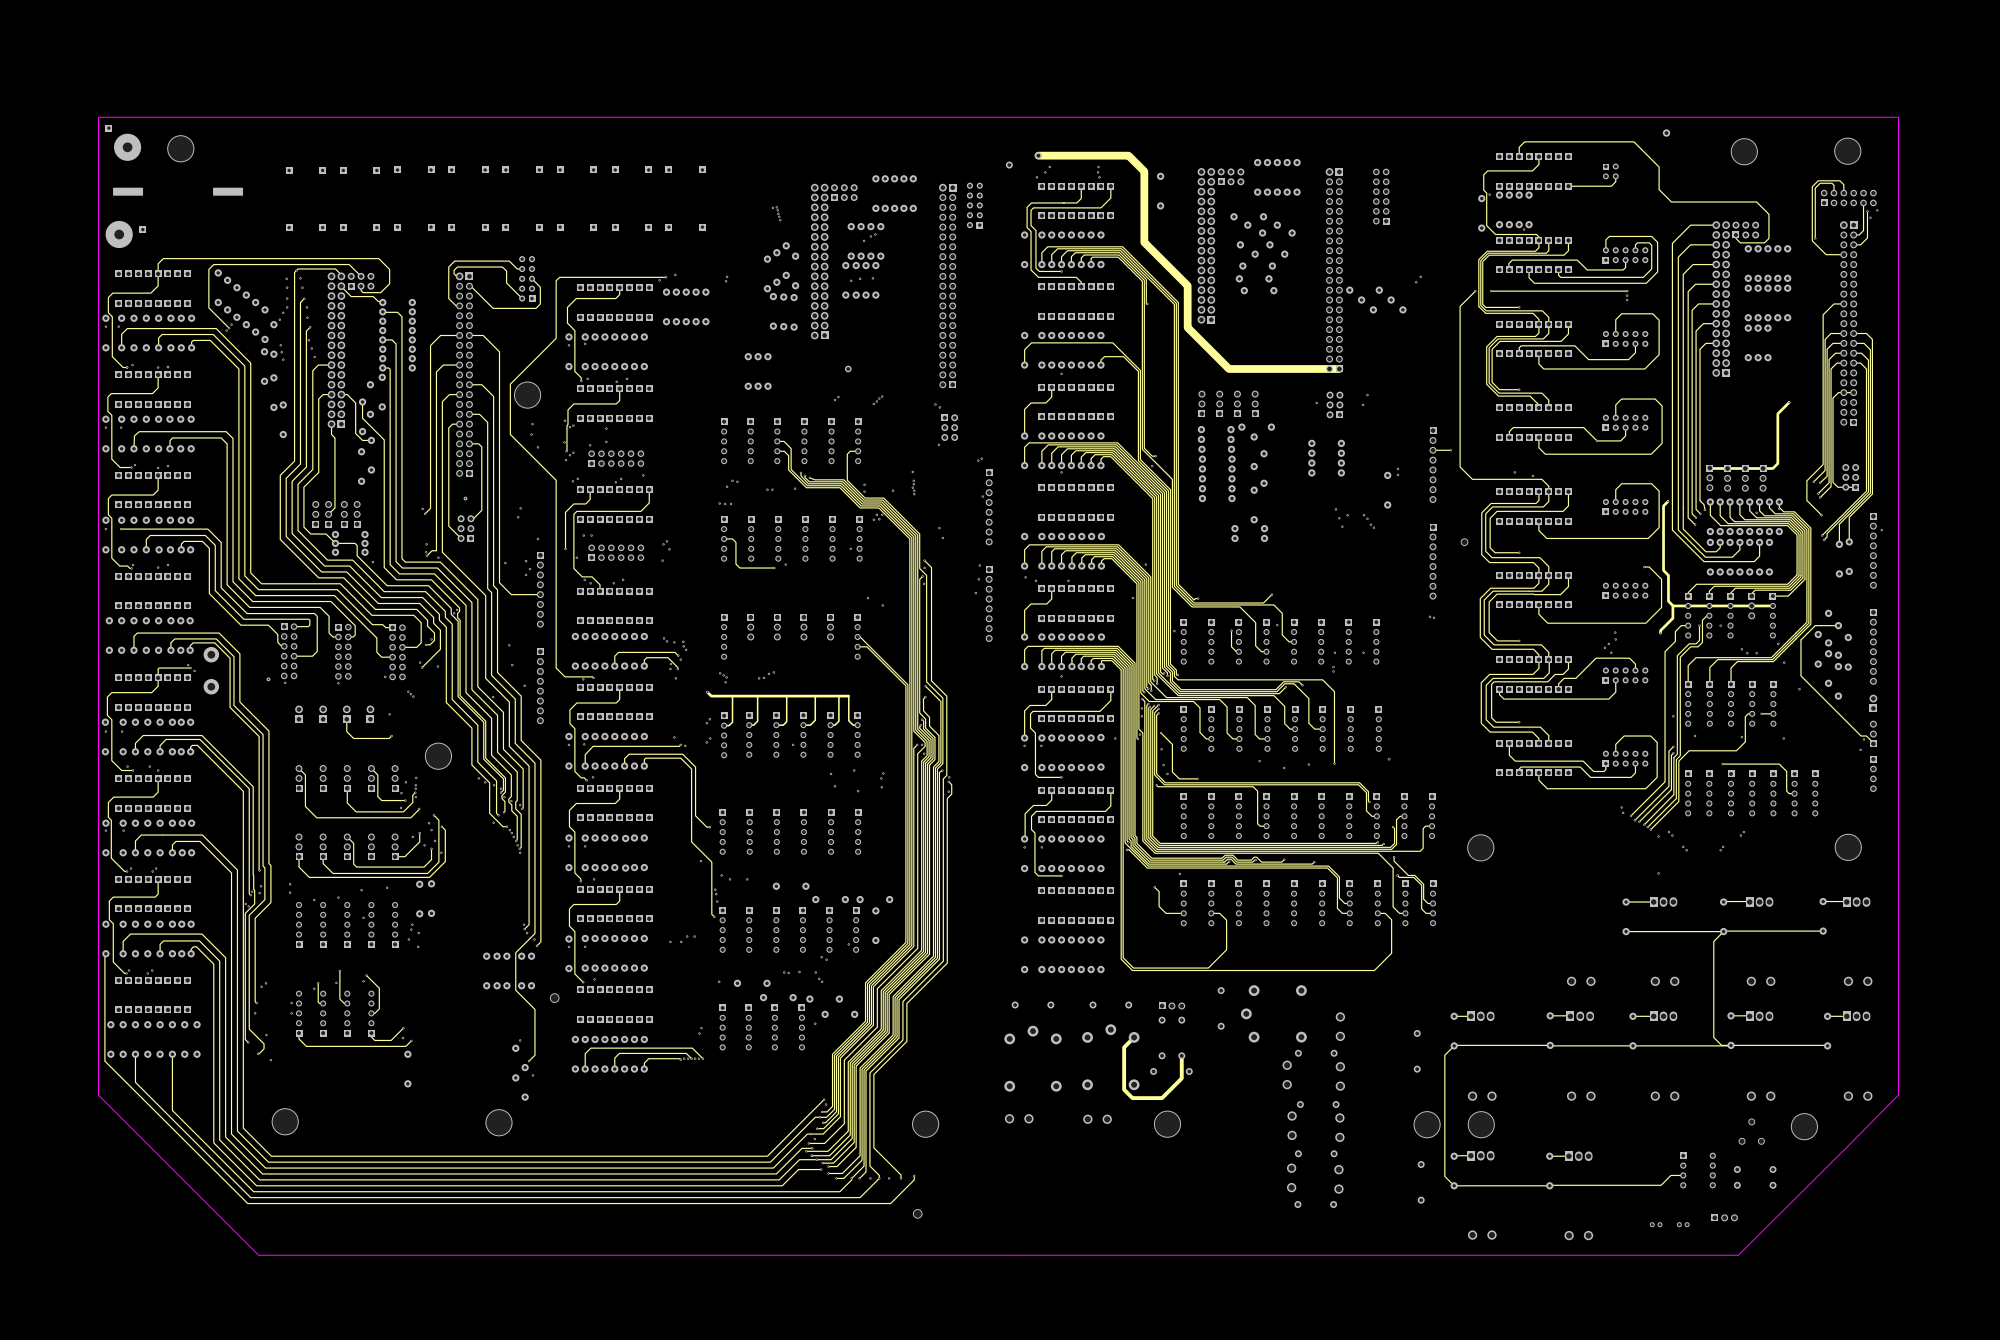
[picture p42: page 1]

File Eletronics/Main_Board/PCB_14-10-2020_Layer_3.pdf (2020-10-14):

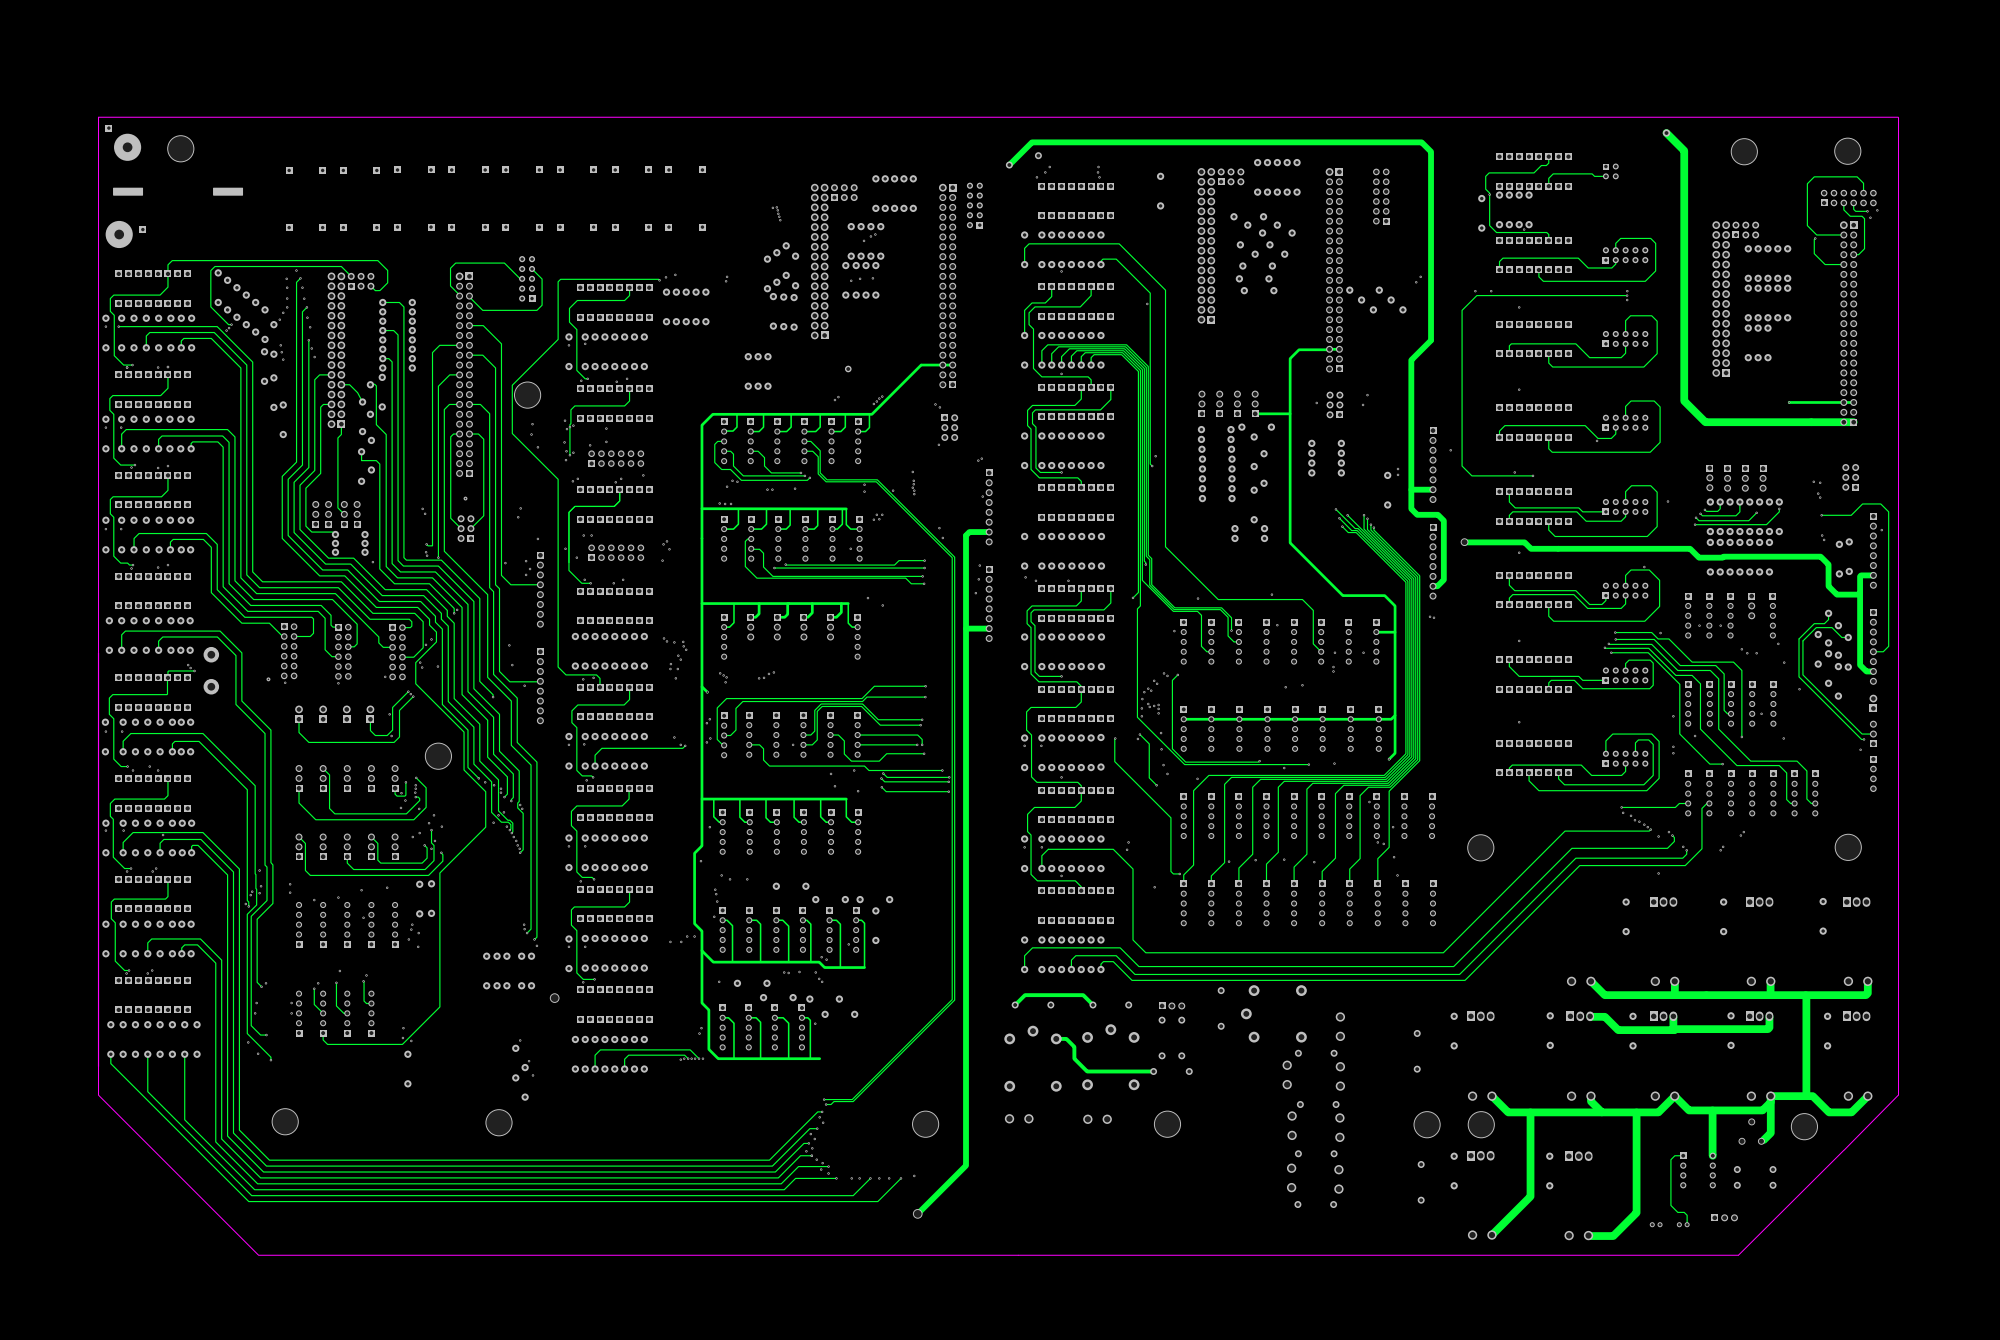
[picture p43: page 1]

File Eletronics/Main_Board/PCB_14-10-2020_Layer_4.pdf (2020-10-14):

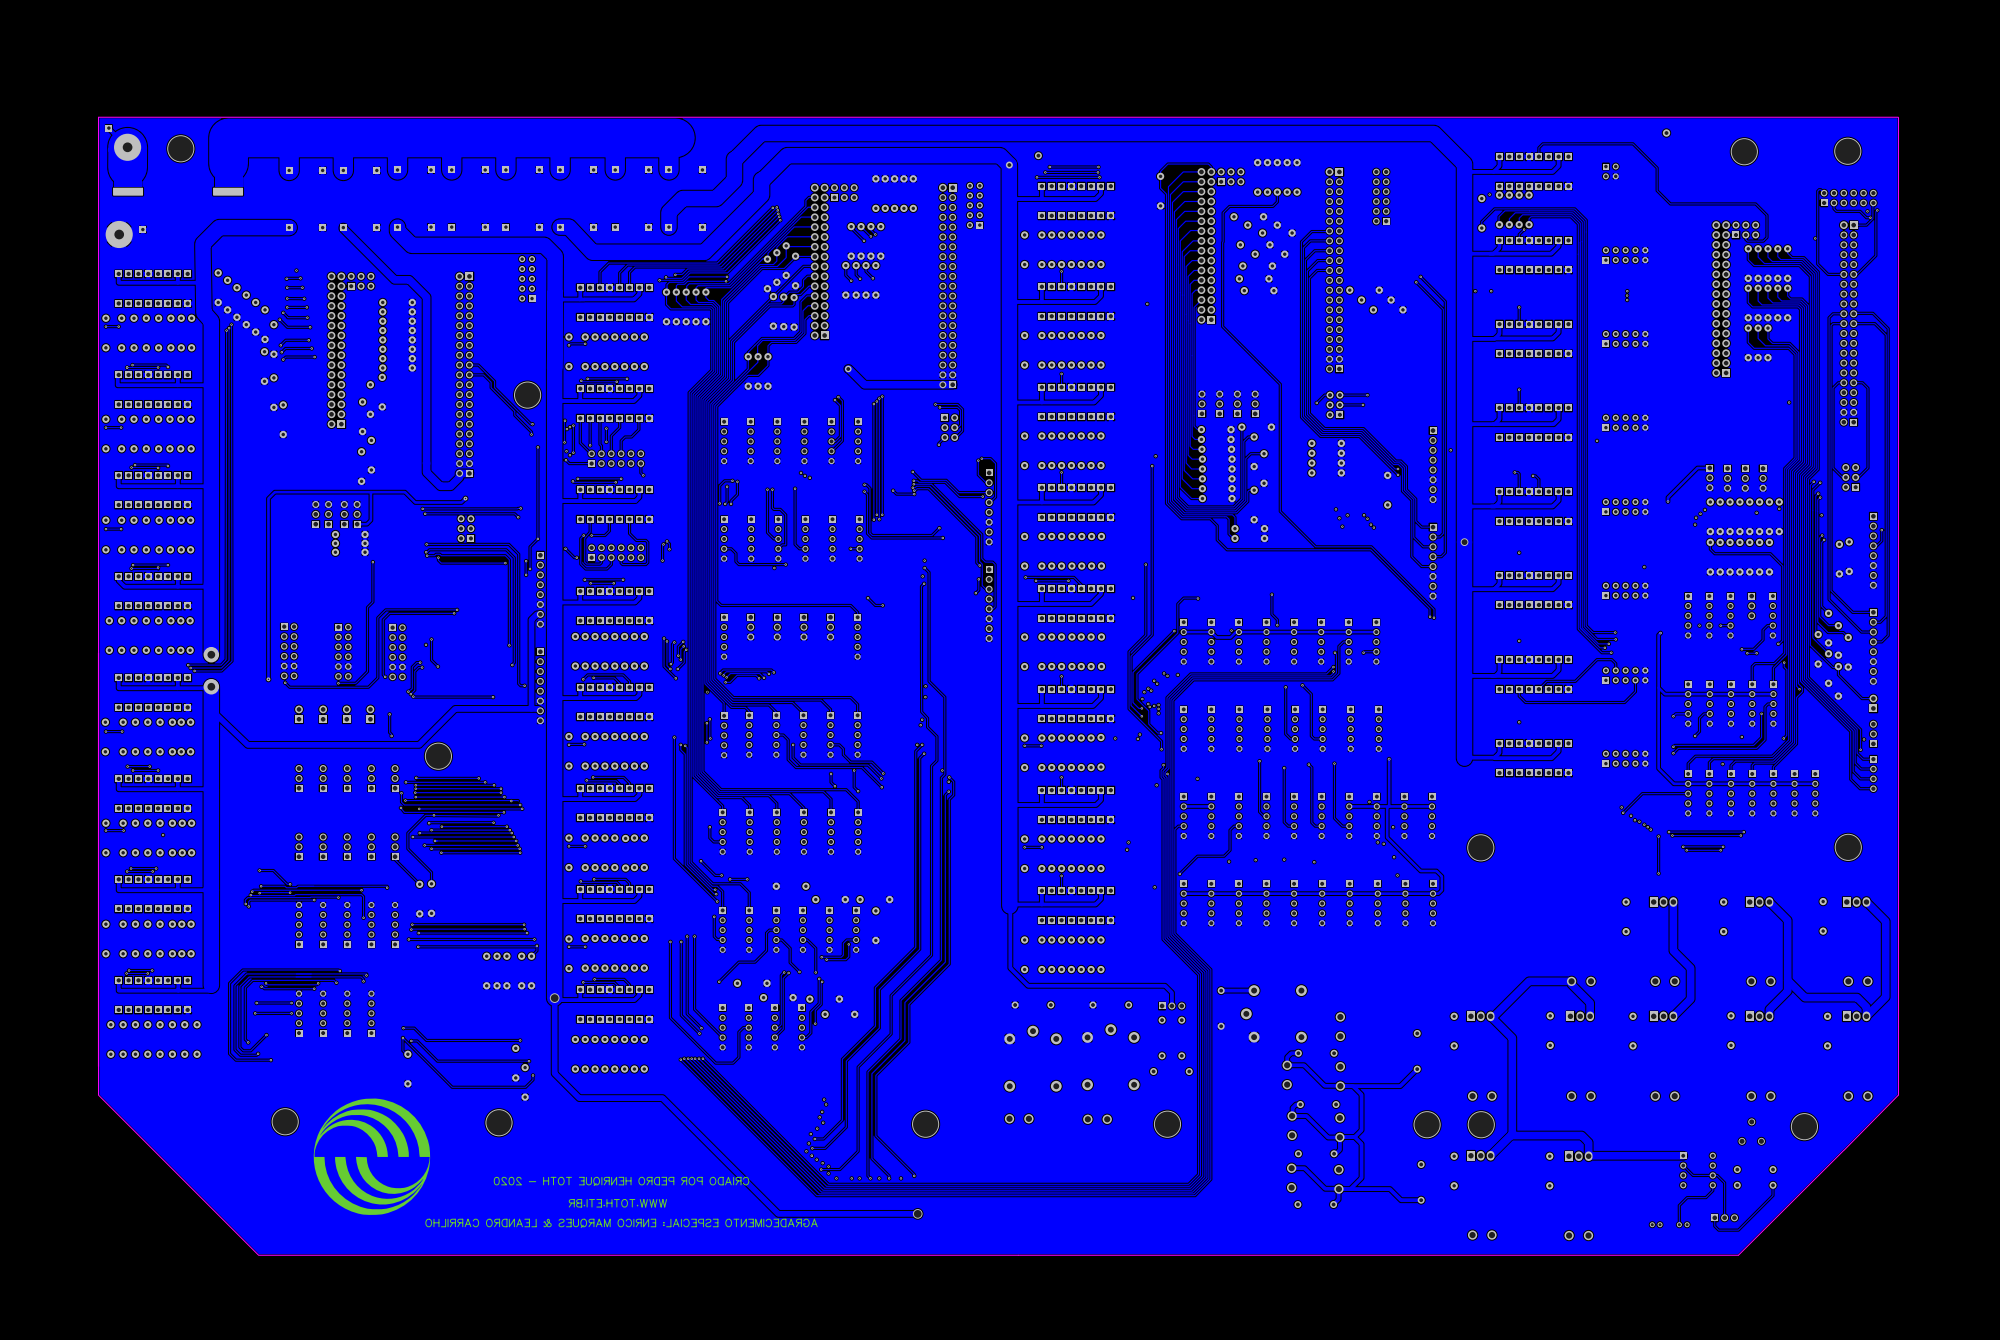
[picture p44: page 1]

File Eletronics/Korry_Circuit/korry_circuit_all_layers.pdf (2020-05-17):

A320

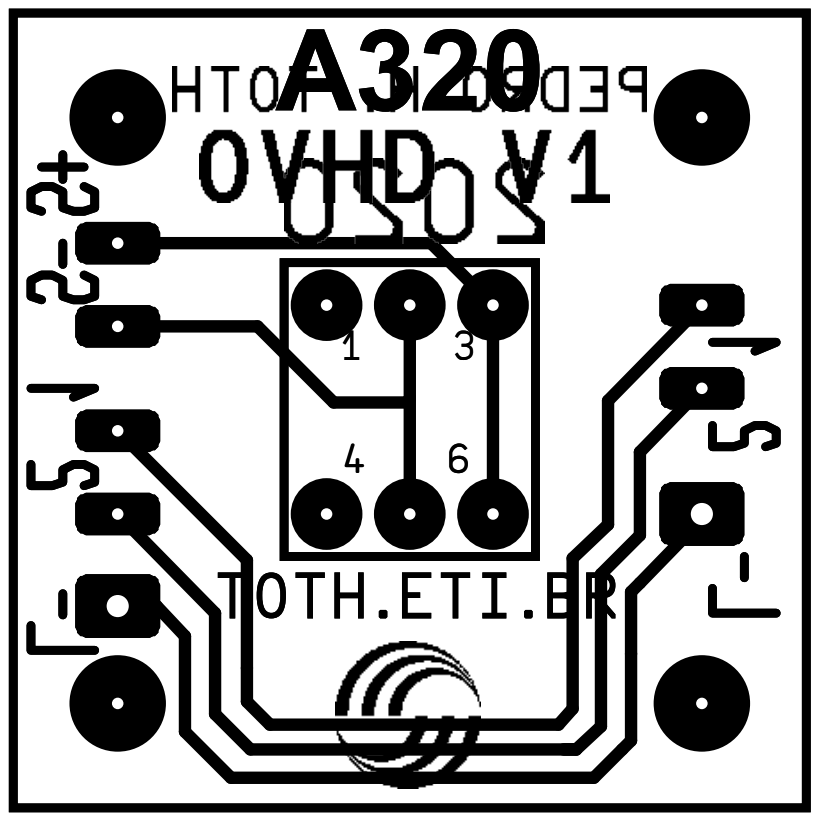
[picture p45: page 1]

TOTH.ETI.BR

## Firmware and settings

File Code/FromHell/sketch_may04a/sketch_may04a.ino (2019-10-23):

#include <oacsp.h>
int pressed = 0;
void setup() {
  OACSP.begin("MyCockpit");
  //OACSP.observeLVar("AB_MPL_FD");
  OACSP.observeLVar("AB_OVH_ELECGENL_FAULT");
  //OACSP.observeLVar("AB_OVH_ELECGENL");
  //OACSP.observeLVar("AB_OVH_ELECGENR");
  // OACSP.observeOffset(0x56CB, OAC::OFFSET_UINT8);
  //OACSP.observeOffset(0x56CC, OAC::OFFSET_UINT8);


  pinMode(13, OUTPUT);
  // pinMode(2, INPUT);


}


void loop() {
  OACSP.pollEvent();
  
  /*
  if (OAC::OffsetUpdateEvent* ev = OACSP.offsetUpdateEvent(0x56CB)) {
    if (ev->value == 1) {
      digitalWrite(13, HIGH);
      delay(500);
      digitalWrite(13, LOW);
      delay(500);
      digitalWrite(13, HIGH);
      delay(500);
      digitalWrite(13, LOW);
      delay(500);
      digitalWrite(13, HIGH);
      delay(500);
      digitalWrite(13, LOW);
      delay(500);
    }
  }

  /*  if (OAC::OffsetUpdateEvent* ev = OACSP.offsetUpdateEvent(0x56CC)) {
    if(ev->value==1) {
     digitalWrite(13, HIGH);
          delay(500);
          digitalWrite(13,LOW);
          delay(500);
          digitalWrite(13, HIGH);
          delay(500);
          digitalWrite(13,LOW);
          delay(500);
          digitalWrite(13, HIGH);
          delay(500);
          digitalWrite(13,LOW);
          delay(500);
    }
    }


    */
    if (OAC::LVarUpdateEvent* ev = OACSP.lvarUpdateEvent("AB_OVH_ELECGENL_FAULT")) {

        if(ev->value==1) {
          digitalWrite(13, HIGH);
        }
        else {
          digitalWrite(13,LOW);
        }
        }
/*
        if (OAC::LVarUpdateEvent* ev = OACSP.lvarUpdateEvent("AB_OVH_PNEUBLEEDAPU")) {

        if(ev->value==1) {
          digitalWrite(13, HIGH);
          delay(500);
          digitalWrite(13,LOW);
          delay(500);
          digitalWrite(13, HIGH);
          delay(500);
          digitalWrite(13,LOW);
          delay(500);
          digitalWrite(13, HIGH);
          delay(500);
          digitalWrite(13,LOW);
          delay(500);
          digitalWrite(13, HIGH);
          delay(500);
          digitalWrite(13,LOW);
          delay(500);
          digitalWrite(13, HIGH);
          delay(500);
          digitalWrite(13,LOW);
          delay(500);

        }
        else {
          digitalWrite(13,LOW);
        }
        }

    int wasPressed = pressed;
    pressed = digitalRead(2);
    if (wasPressed != pressed) {
        OACSP.writeLVar("AB_MPL_FD", pressed);
    }

  */
}

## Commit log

2019-08-21 New model of base and light pannel
    [Base Korry v21.obj, Base Korry v23.obj, Base Korry v24.obj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]
2019-10-23 new prokect files
    [Air Cond v13.dwg, Air Cond v13.dxf, Base Korry_ditch v5.obj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]
2020-04-19 mudanca de estrutura de diretorios
    [A320 PANELES.dwg, Air Cond v13.dwg, Air Cond v13.dxf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]
2020-04-19 eletric panel
    [Elec Panel.dwg, Elec Panel.dxf, Elec Panel.f3d]
2020-04-21 paineis de incendio e hidraulico
    [Fire Panel.dwg, Fire Panel.dxf, Fire Panel.f3d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]
2020-04-21 Paineis do Lado Esquerdo
    [A320 PANELES.dwg, Cargo_Smoke Panel.dwg, Cargo_Smoke Panel.dxf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]
2020-04-21 arquivos antigos apagados
    [A320 PANELES.dwg, cubo_vivo v1.obj]
2020-04-23 Last Files to Cut
    [L_Cargo_Smoke Panel.dwg, L_Cargo_Smoke Panel.dxf, L_Cargo_Smoke Panel.f3d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]
2020-05-03 remodel regular korry
    [Korry Horizontal v4.dwg, Korry Horizontal v4.dxf, Korry Horizontal v4.f3d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]
2020-05-06 new korry switch
    [Korry Horizontal.dwg, Korry Horizontal.dxf, Korry Horizontal.f3d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]
2020-05-13 README update
    [Button List.xlsx, R_EVAC Panel.dwg, R_EVAC Panel.dxf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]
2020-05-17 Korry Eletronic schematics
2020-05-17 Last Panel to add.
    [Extra_Main.dwg, Extra_Main.dxf, Extra_Main.f3d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]
2020-05-20 korry protected base
    [Korry_Protected_Base.dwg, Korry_Protected_Base.dxf, Korry_Protected_Base.f3d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]
2020-05-24 Ajuste de altura
    [Korry_Protected_Base.dwg, Korry_Protected_Base.dxf, Korry_Protected_Base.f3d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]
2020-05-24 Protected Shield
    [Korry_Protected_Shield.dwg, Korry_Protected_Shield.dxf, Korry_Protected_Shield.f3d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]
2020-05-27 New Buttons
    [Korry_Protected_Base.dwg, Korry_Protected_Base.dxf, Korry_Protected_Base.f3d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]
2020-05-27 old files removed
    [Korry_Protected_Base.dwg, Korry_Protected_Base.dxf, Korry_Protected_Base.f3d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]
2020-05-30 New Single PB
    [Button_Body.dwg, Button_Body.dxf, Button_Body.f3d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]
2020-06-01 Renamed Files
    [Button_Base.dwg, Button_Base.dxf, Button_Base.f3d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]
2020-06-02 Update na planilha de botoes
    [Button_List.xlsx]
2020-06-26 Button Exten
    [Button_Extension.dwg, Button_Extension.dxf, Button_Extension.f3d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]
2020-10-14 Novos arquivos das placas
    [PCB_14-10-2020.dxf]
2020-10-29 Lista de Materiais V1
2020-11-13 Updated buttons mapping
    [Button_List.xlsx]
2020-12-20 Paineis para a gravacao a laser
    [AirCond Panel.dwg, Elec Panel.dwg, Fire Panel.dwg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]
2021-02-16 New Code Modules
    [Button_List.xlsx]
2022-08-19 New code for board
    [Button_List.xlsx]
